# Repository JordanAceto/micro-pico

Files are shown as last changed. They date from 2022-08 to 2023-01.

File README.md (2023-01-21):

# Micro-Pico tiny monosynth

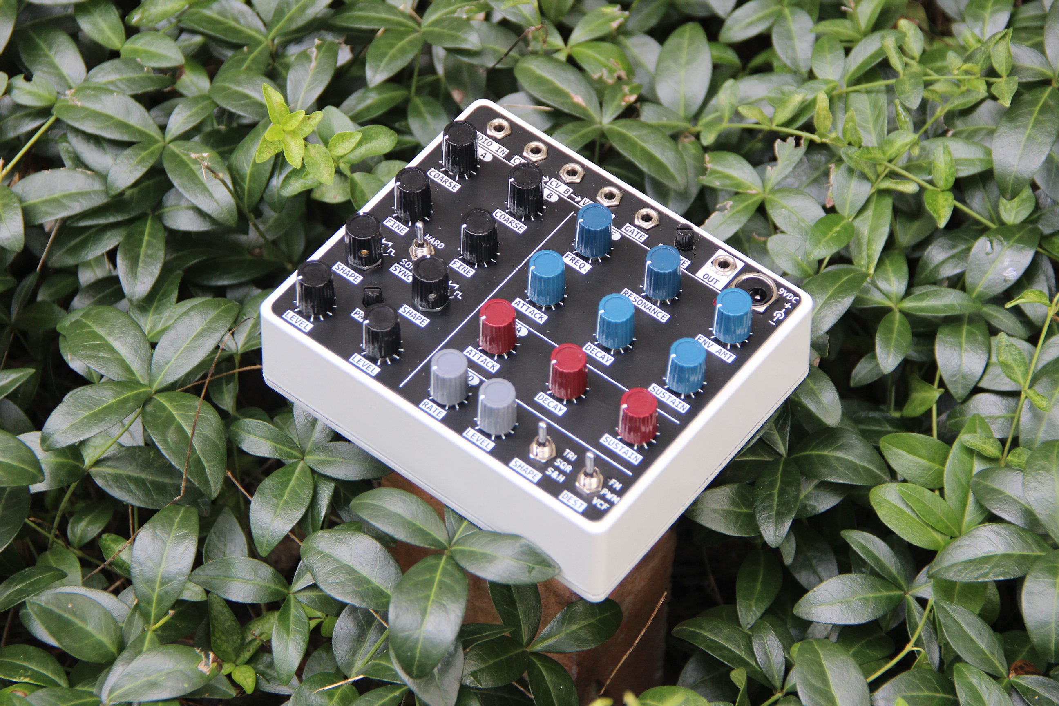
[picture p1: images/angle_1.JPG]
front angle finished synth


## A lil' analog synth with:
- Two SSI2130 VCOs
    - sine, triangle, sawtooth, and pulse waves available
    - VCO B can by syncronized to VCO A (hard and soft sync available)
    - the VCOs share a single manual pulse width control
- Two minimoog style ADS envelope generators
    - These envelopes cycle through all four A, D, S, and R stages, but the Decay and Release stages share a single potentiometer
- Modulation LFO
    - triangle, square, and sample & hold waveforms
    - can be routed to VCO FM, PWM, or VCF modulation
    - `MOD CV` input controlls the LFO depth along with the LFO `LEVEL` knob, for mod-wheel antics
- Swappable VCF port
    - the VCF can be changed by plugging in a variety of [VCF plug-in boards](https://github.com/JordanAceto/VCF_plug_in_boards)
    - you need at least one of the above VCF boards to finish the synth
- Final linear VCA
    - simple linearized SSI2162 VCA
- Extra patch points on the pcb for mods and experimentation
    - independent aux FM inputs for the VCOs [-5v, +5v]
    - aux PWM CV [-5v, +5v]
    - aux VCF cutoff CV [-5v, +5v]
    - aux VCA amplitude CV [0v, +5v]
    - white noise out [-5v, +5v]
    - patch points for most of the important signals
- Powered with a standard guitar pedal style 9VDC center negative adapter
    - current draw is approximately 220mA **without** a VCF plug-in board installed
    - expect another 100mA or so depending on the VCF board used
    - so use a 9v adapter with at least 500mA capacity or greater

The feature set is quite limited. The emphasis is on small, simple, and all-analog signal path. A fun little jammer to hook up to a sequencer or CV keyboard.

## Construction notes:
- It is easier to install the trimpots, VCF port headers, and various through-hole parts before installing the pots and switches
    - you can still get to everything if you forget, or need to change something later
- When installing the front panel components
    - dry fit all of the pots, switches, and jacks before soldering
    - the rotary switches need a nut or spacer under the panel to match the height of the pots
    - the 9VDC connector needs a nut or spacer under the panel, and needs to be lifted off the board a little, so that it protrudes far enough to tighten the outer nut
    - tighten down all of the components, check for alighment and height issues, and only then start soldering
- The rotary switches need a sleeve adapter for the knobs to fit nicely
    - something like [this](https://www.amplifiedparts.com/products/potentiometer-adapter-sleeve-converts-6mm-or-18t-shaft-14)
    - or use a bit of tubing if you're DIY happy
- It's designed to fit in a Hammond 1590XX aluminum box
    - these are available pre-painted in a few colors
    - with a VCF plug-in board installed, the 1590XX is the *teensiest* bit too short, the trimpots hit the lid when tightened
        - you can put some 2mm-ish washers between the lid and the box
        - eventually I hope to make a gasket that adds a few mm height and looks cleaner
        - or it could even have an acrylic light plate like some people do with pedals
    - other chassis at least as big as the 1590XX (plus a few mm taller) could work

## Calibration:
- follow the [SSI2130 datasheet](https://www.soundsemiconductor.com/downloads/ssi2130datasheet.pdf) Tuning Process for the VCOs, or tune by ear
- calibrate the VCF according to the instructions on the main VCF plug-in board repo
- check that the white noise is about +/-5V in amplitude. You can try different BJTs or mess with the gain setting resistors, but as long as it's reasonably close the S&H setting will sound fine, it's not critical

## Status:
Safe to build!

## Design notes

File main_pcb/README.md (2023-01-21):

# Main PCB for tiny monosynth

## [SCHEMATIC](https://github.com/JordanAceto/micro-pico/blob/main/main_pcb/docs/micro_pico-schematic.pdf)

Open `index.html` in a web browser for easy documentation navigation.

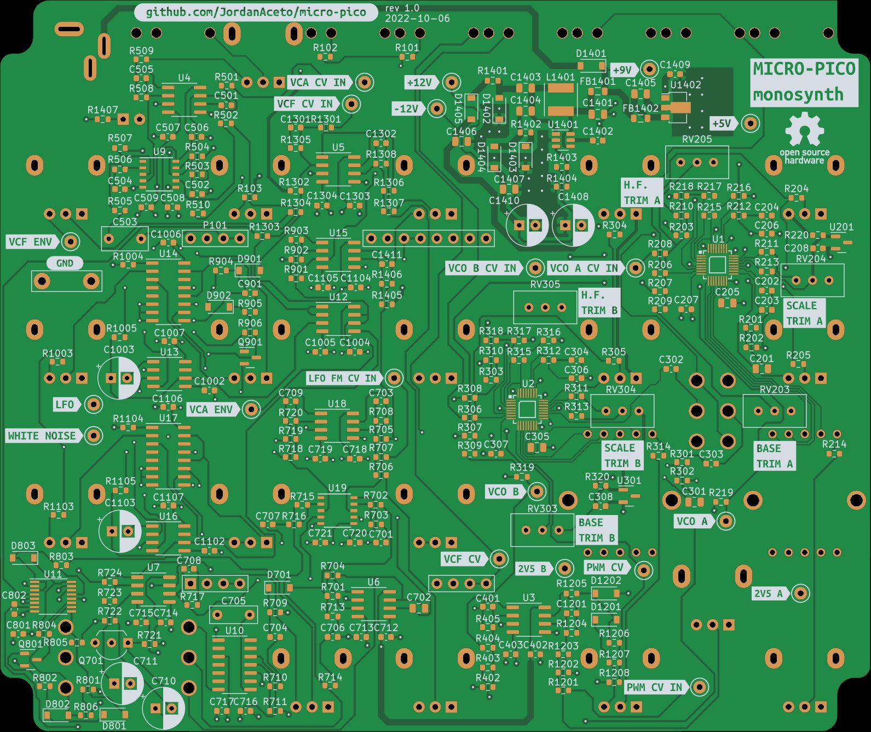
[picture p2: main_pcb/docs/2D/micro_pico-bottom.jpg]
pcb render


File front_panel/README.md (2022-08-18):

# Cheap and cheerful PCB front panel

KiCad 6 project and gerber files for making a front panel.

Open `index.html` in a web browser for easy documentation navigation.

## Important:
- The faceplate material should be 0.8mm or thinner. This ensures that the threaded panel components protrude far enough through the metal faceplate and pcb panel sandwich, so the nuts can be tightened.

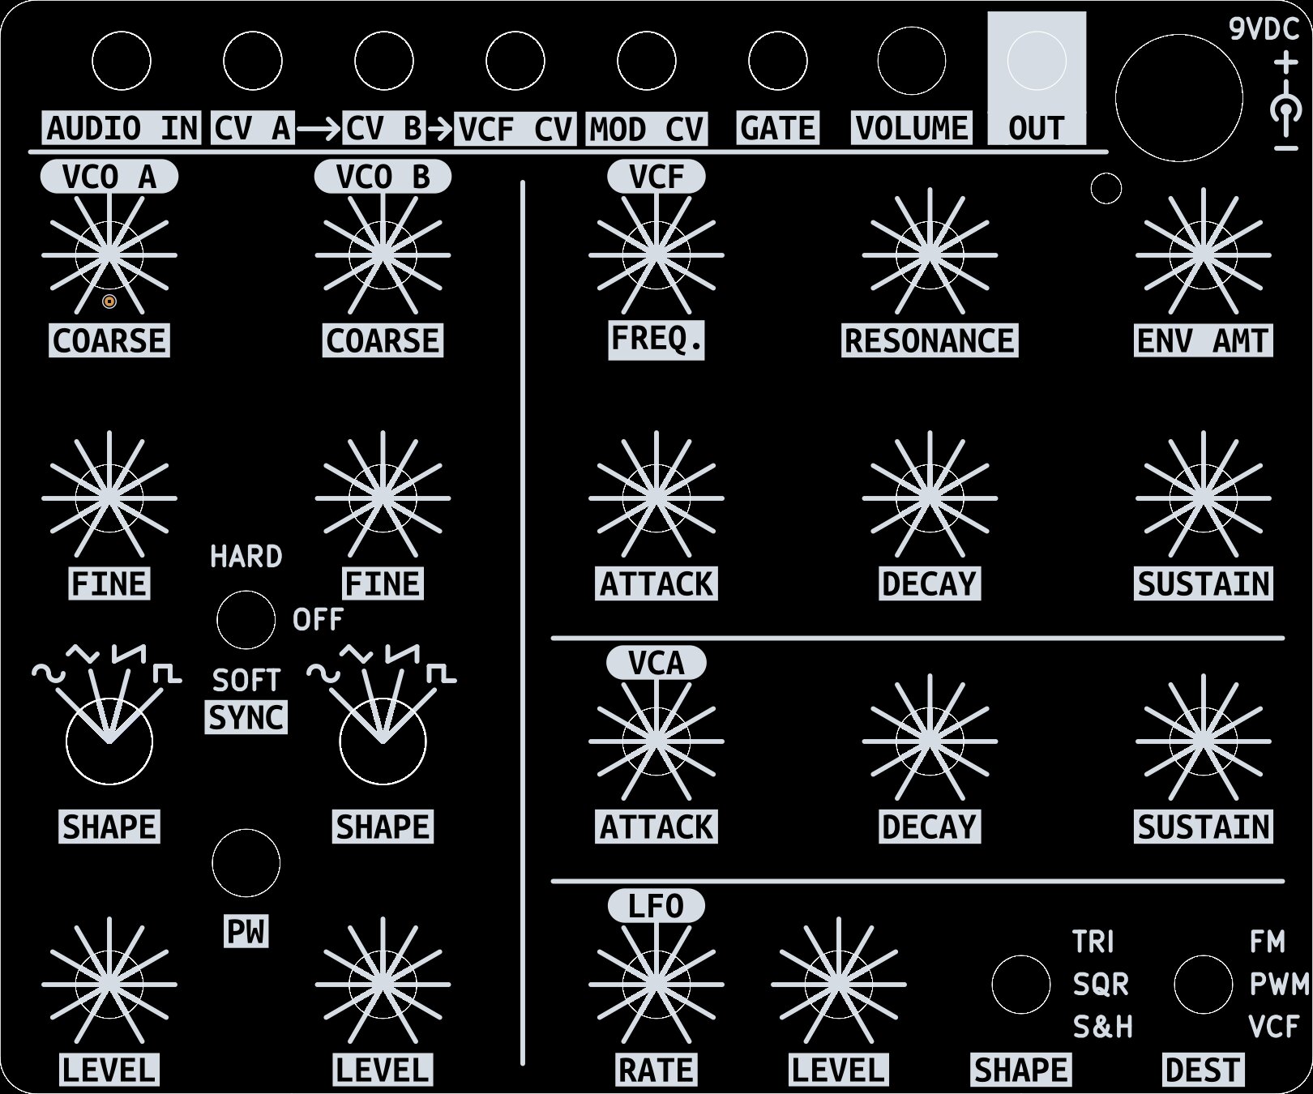
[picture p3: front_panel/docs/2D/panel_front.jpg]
panel render


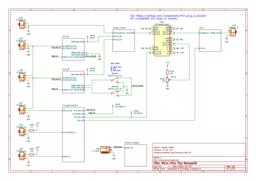
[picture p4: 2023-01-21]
main_pcb/docs/html_nav/images/cat_Schematic_micro_pico-schematic.png

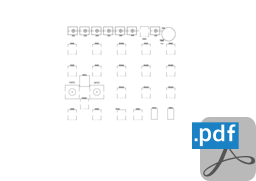
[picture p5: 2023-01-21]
main_pcb/docs/html_nav/images/cat_pdf_layers_micro_pico-F_Silkscreen.png

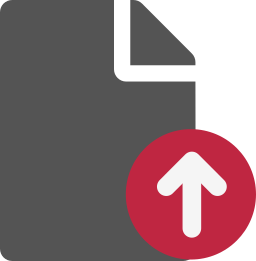
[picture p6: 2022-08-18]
main_pcb/docs/html_nav/images/export_256.png

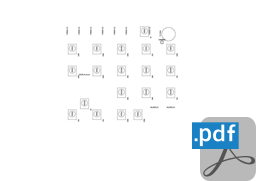
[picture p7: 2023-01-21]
main_pcb/docs/html_nav/images/cat_pdf_layers_micro_pico-F_Fab.png

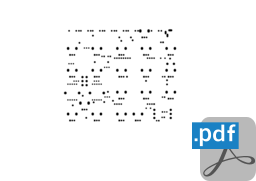
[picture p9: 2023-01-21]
main_pcb/docs/html_nav/images/cat_pdf_layers_micro_pico-F_Mask.png

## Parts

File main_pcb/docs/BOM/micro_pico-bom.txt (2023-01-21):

Row	Description	Part	References	Value	Footprint	Quantity Per PCB	Status	Datasheet
1	Unpolarized capacitor	C	C401 C505 C708 C901 C1302	100p	C_0603_1608Metric	5	 	~
2	Unpolarized capacitor	C	C501 C502 C504 C701 C703 C704 C707 C709 C1002 C1102 C1201 C1301	1n	C_0603_1608Metric	12	 	~
3	Unpolarized capacitor	C	C705	2n2	C_Rect_L7.2mm_W2.5mm_P5.00mm_FKS2_FKP2_MKS2_MKP2	1	 	~
4	Unpolarized capacitor	C	C205 C305	3N9 COG	C_0805_2012Metric	2	 	~
5	Unpolarized capacitor	C	C202 C203 C204 C302 C303 C304	10n	C_0603_1608Metric	6	 	~
6	Unpolarized capacitor	C	C702	10n	C_0805_2012Metric	1	 	~
7	Unpolarized capacitor	C	C206 C207 C208 C306 C307 C308 C402 C403 C506 C507 C508 C509 C706 C712 C713 C714 C715 C716 C717 C718 C719 C720 C721 C801 C802 C1004 C1005 C1006 C1007 C1104 C1105 C1106 C1107 C1303 C1304 C1402 C1409 C1411	100n	C_0603_1608Metric	38	 	~
8	Unpolarized capacitor	C	C1405	470n	C_0805_2012Metric	1	 	~
9	Unpolarized capacitor	C	C503	470n	C_Rect_L7.0mm_W3.5mm_P5.00mm	1	 	~
10	Unpolarized capacitor	C	C1403 C1404	1u	C_0805_2012Metric	2	 	~
11	Unpolarized capacitor	C	C1401 C1406 C1407	4u7	C_0805_2012Metric	3	 	~
12	Polarized capacitor	C_Polarized	C710 C711 C1003 C1103 C1408 C1410	10u	CP_Radial_D6.3mm_P2.50mm	6	 	~
13	Unpolarized capacitor	C	C201 C301	10u	C_0805_2012Metric	2	 	~
14	75V 0.15A Fast Switching Diode, SOD-123	1N4148W	D701 D801 D802 D803 D901 D902 D1201 D1202	1N4148W	D_SOD-123	8	 	https://www.vishay.com/docs/85748/1n4148w.pdf
15	Schottky diode	D_Schottky	D1401 D1402 D1403 D1404 D1405	B5819W	D_SOD-123	5	 	~
16	Light emitting diode	LED	D1406	XLMDK65D	LED_D3.0mm	1	 	~
17	Ferrite bead, small symbol	FerriteBead_Small	FB1401 FB1402	100R @ 100MHz	L_0805_2012Metric	2	 	~
18	DC Barrel Jack with an internal switch	PJ-011A	J108	PJ-011A	CUI_PJ-011A	1	 	~
19	Audio Jack, 2 Poles (Mono / TS), Switched T Pole (Normalling)	PJ301M-12	J101 J102 J103 J104 J105 J106 J107	PJ301M-12	PJ301M-12	7	 	~
20	Inductor symbol for simulation only	INDUCTOR	L1401	10uH, 1.2A	L_Taiyo-Yuden_NR-50xx	1	 	~
21		VCF_plug_in_port	P101	VCF_plug_in_port	VCF_plug_in_port	1	 	
22	0.2A Ic, 40V Vce, Small Signal NPN Transistor, TO-92	2N3904_wide	Q701	2N3904_wide	TO-92_Inline_Wide	1	 	https://www.onsemi.com/pub/Collateral/2N3903-D.PDF
23	0.2A Ic, 40V Vce, Small Signal NPN Transistor, SOT-23	MMBT3904	Q801 Q901	MMBT3904	SOT-23	2	 	https://www.onsemi.com/pub/Collateral/2N3903-D.PDF
24	Resistor	R	R1401 R1402	1	R_0603_1608Metric	2	 	~
25	Resistor	R	R1004 R1005 R1104 R1105	100	R_0603_1608Metric	4	 	~
26	Resistor	R	R212 R312 R503 R506 R509 R703 R716	270	R_0603_1608Metric	7	 	~
27	Resistor	R	R101 R220 R320 R723 R803 R1205	1k	R_0603_1608Metric	6	 	~
28	Resistor	R	R215 R315	3k9	R_0603_1608Metric	2	 	~
29	Resistor	R	R216 R218 R316 R318 R507 R711	4k7	R_0603_1608Metric	6	 	~
30	Resistor	R	R1003 R1103	5k6	R_0603_1608Metric	2	 	~
31	Resistor	R	R1208	6k8	R_0603_1608Metric	1	 	~
32	Resistor	R	R102 R103 R201 R202 R301 R302 R709 R801 R802 R804 R805 R806 R904 R906 R1206 R1407	10k	R_0603_1608Metric	16	 	~
33	Resistor	R	R217 R317 R508 R710 R902	12k	R_0603_1608Metric	5	 	~
34	Resistor	R	R1404	13k3	R_0603_1608Metric	1	 	~
35	Resistor	R	R219 R319	18k	R_0603_1608Metric	2	 	~
36	Resistor	R	R702 R1305	22k	R_0603_1608Metric	2	 	~
37	Resistor	R	R403 R404 R505	27k	R_0603_1608Metric	3	 	~
38	Resistor	R	R203 R303 R708	39k	R_0603_1608Metric	3	 	~
39	Resistor	R	R211 R311 R713 R714	47k	R_0603_1608Metric	4	 	~
40	Resistor	R	R720 R1207 R1304	56k	R_0603_1608Metric	3	 	~
41	Resistor	R	R705	68k	R_0603_1608Metric	1	 	~
42	Resistor	R	R206 R207 R208 R209 R214 R306 R307 R308 R309 R314 R402 R405 R501 R504 R704 R706 R715 R717 R718 R719 R901 R903 R905 R1301 R1302 R1303 R1306 R1308 R1405 R1406	100k	R_0603_1608Metric	30	 	~
43	Resistor	R	R1403	114k	R_0603_1608Metric	1	 	~
44	Resistor	R	R502 R721	150k	R_0603_1608Metric	2	 	~
45	Resistor	R	R204 R304 R707	200k	R_0603_1608Metric	3	 	~
46	Resistor	R	R701 R1203 R1204 R1307	220k	R_0603_1608Metric	4	 	~
47	Resistor	R	R210 R310	270k	R_0603_1608Metric	2	 	~
48	Resistor	R	R1201 R1202	330k	R_0603_1608Metric	2	 	~
49	Resistor	R	R213 R313	470k	R_0603_1608Metric	2	 	~
50	Resistor	R	R205 R305 R722	2M2	R_0603_1608Metric	3	 	~
51	Resistor	R	R510 R724	10M	R_0603_1608Metric	2	 	~
52	Potentiometer	R_Potentiometer	RV501 RV1201	5k	Bourns_PTV09	2	 	~
53	Trim-potentiometer	R_Potentiometer_Trim	RV203 RV204 RV205 RV303 RV304 RV305	5k	Potentiometer_Bourns_3296W_Vertical	6	 	~
54	Potentiometer	R_Potentiometer	RV101 RV206 RV306 RV1003 RV1103	10k	Alpha_RD901F	5	 	~
55	Potentiometer	R_Potentiometer	RV201 RV202 RV301 RV302 RV601 RV602 RV701 RV1301	100k	Alpha_RD901F	8	 	~
56	Potentiometer	R_Potentiometer	RV1001 RV1002 RV1101 RV1102	1MA	Alpha_RD901F	4	 	~
57	3 rotary switches with 4 positions	SR1712F-0204	SW201 SW301	SR1712F-0204	SR1712F_rotary_switch	2	 	
58	Switch, dual pole double throw, separate symbols	SW_DP_on_on_on	SW101	SW_DP_on_on_on	DPDT_mini_toggle	1	 	~
59	Switch, single pole double throw, center OFF position	SW_SPDT_MSM	SW701 SW801	SW_SPDT_CO	SPDT_mini_toggle	2	 	~
60	CMOS double 4-channel analog multiplexer/demultiplexer, TSSOP-16/DIP-16/SOIC-16	CD4052B	U14 U17	CD4052B	SOIC-16_3.9x9.9mm_P1.27mm	2	 	http://www.ti.com/lit/ds/symlink/cd4052b.pdf
61	Triple analog Multiplexer 2 to 1 line	4053	U11	CD4053	TSSOP-16_4.4x5mm_P0.65mm	1	 	http://www.intersil.com/content/dam/Intersil/documents/cd40/cd4051bms-52bms-53bms.pdf
62	Positive 100mA 30V Linear Regulator, Fixed Output 5V, SOT-89	L78L05_SOT89	U1402	L78L05_SOT89	SOT-89-3	1	 	http://www.st.com/content/ccc/resource/technical/document/datasheet/15/55/e5/aa/23/5b/43/fd/CD00000446.pdf/files/CD00000446.pdf/jcr:content/translations/en.CD0000044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
63	Sample And Hold Unity Gain Follower, SOIC-14	LF398_SOIC14	U10	LF398_SOIC14	SOIC-14_3.9x8.7mm_P1.27mm	1	 	http://www.ti.com/lit/ds/symlink/lf398-n.pdf
64	2.500V Precision Micropower Shunt Voltage Reference, SOT-23	LM4040DBZ-2.5	U201 U301	LM4040C-2.5	SOT-23	2	 	http://www.ti.com/lit/ds/symlink/lm4040-n.pdf
65		LT3467A	U1401	LT3467A	TSOT-23-6	1	 	
66		SSI2130	U1 U2	SSI2130	PQN32_HandSoldering	2	 	
67		SSI2162	U9 U19	SSI2162	SSOP-10_3.9x4.9mm_P1.00mm	2	 	https://www.soundsemiconductor.com/downloads/ssi2162datasheet.pdf
68	Dual Low-Noise JFET-Input Operational Amplifiers, DIP-8/SOIC-8	TL072	U3 U4 U5 U6 U7 U12 U15 U18	TL072	SOIC-8_3.9x4.9mm_P1.27mm	8	 	http://www.ti.com/lit/ds/symlink/tl071.pdf
69	Timer, 555 compatible, SOIC-8	LM555xM	U13 U16	TLC555	SOIC-8_3.9x4.9mm_P1.27mm	2	 	

Project info:
Schematic:	micro_pico
Variant:	default
Revision:	1.0
Date:	2022-10-06
KiCad Version:	6.0.5+dfsg-1~bpo11+1
Statistics:
Component Groups:	69
Component Count:	282 (221 SMD/ 48 THT)
Fitted Components:	282 (221 SMD/ 48 THT)
Number of PCBs:	1
Total Components:	282

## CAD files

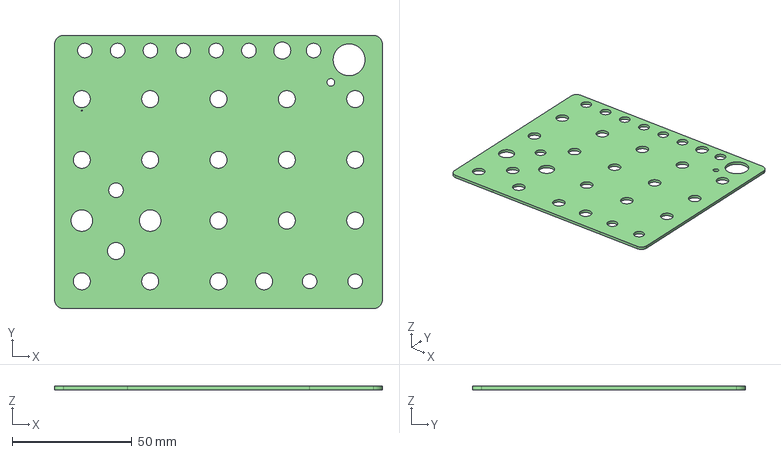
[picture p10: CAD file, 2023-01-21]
front_panel/docs/CAD/micro_pico_faceplate-3D.step
137.2 x 114.3 x 1.60 mm

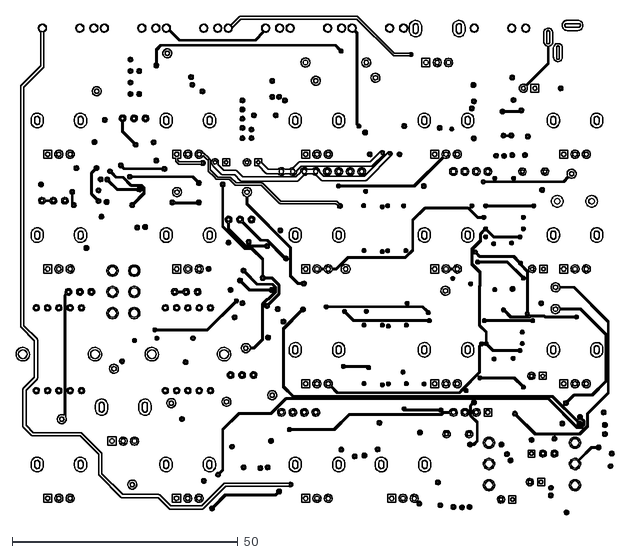
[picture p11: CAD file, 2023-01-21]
main_pcb/docs/CAD/micro_pico-F_Cu.dxf
132.4 x 110.3

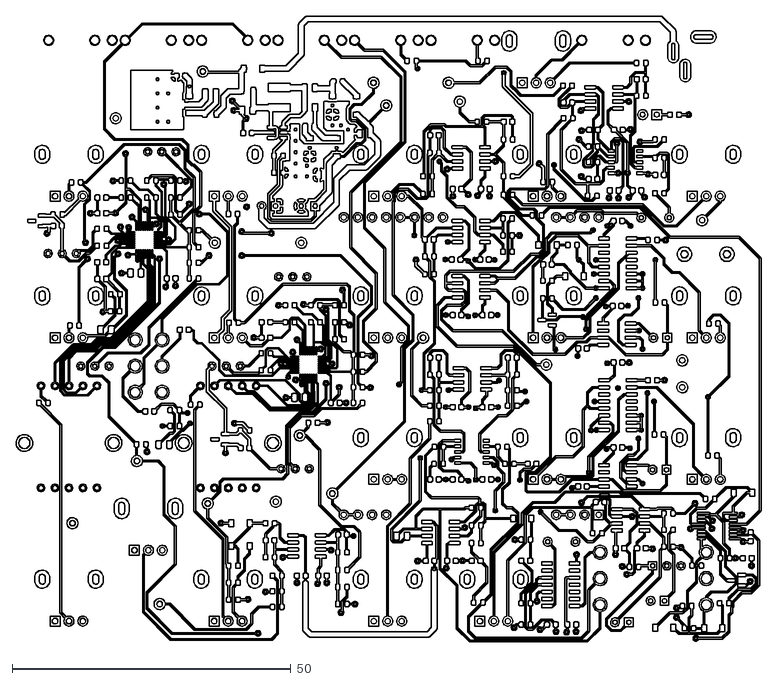
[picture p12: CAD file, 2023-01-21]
main_pcb/docs/CAD/micro_pico-B_Cu.dxf
133.6 x 112.2

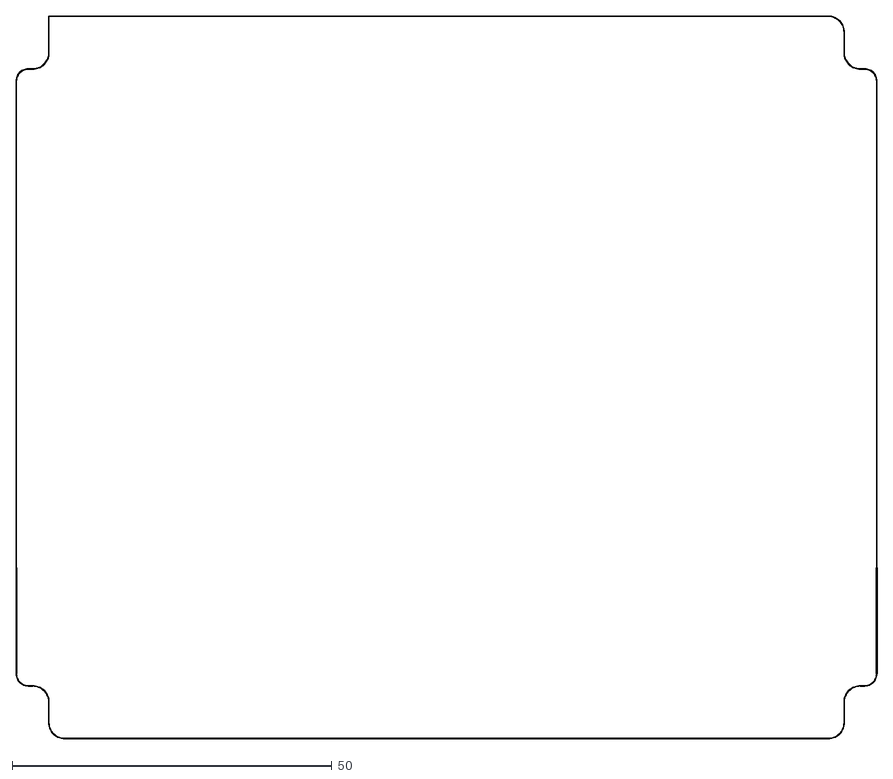
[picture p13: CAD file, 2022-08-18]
main_pcb/docs/CAD/micro_pico-Edge_Cuts.dxf
134.7 x 113.1

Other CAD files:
main_pcb/docs/CAD/micro_pico-B_Mask.dxf
main_pcb/docs/CAD/micro_pico-F_Mask.dxf
main_pcb/docs/CAD/micro_pico-F_Silkscreen.dxf

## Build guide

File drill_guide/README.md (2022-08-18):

# Drill guide for the front panel holes

Print out 1-to-1 and double sticky tape to the front panel to locate the drill holes.

On my printer, I have the best luck getting the scaling right by printing the gerber file from KiCads gerber viewer.

drill guide

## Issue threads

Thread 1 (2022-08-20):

VCA tails are a bit abrupt with low volume settings

JordanAceto, 2022-08-20:
On the final VCA, resistor R510 ensures that when zero volts is applied to the CV input, the output signal is completely silenced. It "pushes down" the CV input by a tiny bit.

But if too much current flows through this resistor, it can make the long tails of the volume envelope end abruptly. The final decay doesn't sound as smooth as it should.

Since 10M is already a very large resistor value, it would be an improvement to move this resistor to the -2V5 reference voltage. This will reduce the effect of the push-down resistor, and if we find that there is bleedthrough with zero CV, we can decrease the resistor a little bit.

This should allow us some flexibility while being able to use common resistor values.

Another way to tackle this might be to change the way the volume pot works: right now the volume pot turns up and down the control voltage that goes to the final VCA. This means when the volume is turned down low, the ADSR signal is small relative to the impact of the push-down resistor. If instead we always sent the ADSR signal to the VCA CV full-strength, and then attenuated the signal before or after the VCA, I think the un-smooth decay effect would be reduced.

As a side benefit of the "attenuate the signal instead of the CV" approach: there is an aux VCA CV input on the PCB, if we use that input the way it's wired now, the volume control will have no effect. If we change to a signal attenuator, then the volume control will always work no matter the CV source.

JordanAceto, 2022-09-09:
Done, changed the way the volume pot works, now it attenuates the final audio out instead of the control signal. Left the 10M push-down resistor in, it is not a problem with the new arrangement.

Closed 2022-09-09.

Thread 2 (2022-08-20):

Volume pot and manual Pulse Width pot are different type

JordanAceto, 2022-08-20:
Most of the potentiometers use common alpha RD901F style pots with a knob attached.

The master volume pot and manual pulse width pot are very cramped for space, so they use pots with knurled plastic shafts, intended to be turned with no knob attached. I used [bourns PTV09A](https://www.bourns.com/pdfs/PTV09.pdf) pots on the prototype build, anything similar to this would work.

This is not currently reflected in any of the schematic, pcb layout, or BOM files, all the pots are listed as the same RD901F style.

Also, the Bourns pots I used had snap-in tabs that were a little bit too wide to fit in the RD901F footprint, I had to clip a tiny bit off the sides of the snap-in tabs to get them to fit.

Update the files so the correct type of pot is specified for the master volume and manual PW pot, and update the footprints for these two pots with slightly longer snap-in tab slots so we don't need to mess around when installing the pots.

JordanAceto, 2022-09-09:
Done, changed footprints for the knob-less pots.

Closed 2022-09-09.

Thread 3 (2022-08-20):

VCOs occasionally frequency lock

JordanAceto, 2022-08-20:
When the two VCOs are tuned very close to each other, they *sometimes* lock together, instead of beating slowly.

This isn't something super noticeable while you're playing it, but it would be better if you could dial in nice slow beat frequencies all the time.

I imagine this is happening via coupling through the 2v5 reference voltage which they share.

Maybe they should each get their own 2v5 reference? The LM4040 used are not super expensive, and they are small so board real estate is not a big deal.

You might also be able to put a little more current through the +2v5 ref LM4040 and see if that helps.

Something else that *might* help is to remove the extra 2v5 ref loads, a few pots and such use the 2v5 ref. We could use an opamp buffer to decouple the 2v5 ref which goes to the SSI2130 `vref` pin and the 2v5 which goes to the pots and stuff. Note that we use two opamp comparators for the ADSR gate inputs, but really they could share one, we could free up an opamp from there if needed.

Investigate and find a good solution. The **best** one would be to just run the LN4040 a little hotter *if it fixes it*, because this doesn't require any new parts or pcb changes.

JordanAceto, 2022-09-08:
After some investigation, I believe the frequency locking is actually coming from the SYNC switch. The VCO_A_PULSE signal is being capacitively injected into the VCO B SOFT_SYNC_IN pin.

Pulling the VCO B SOFT_SYNC_IN pin to ground with a resistor seems to help. On the current prototype there is a 1k ohm resistor kludged from the VCO B SSI2132 soft sync pin to ground. This helps, but does not prevent unwanted syncing all the time. Hard-grounding the soft-sync capacitor does seem to reliably prevent it. The higher the frequency of the VCOs, the more likely they are to sync.

Maybe I need a fancier switch which can ground the sync inputs when sync is off? I'm not even that huge of a sync-lover, maybe there should just be one option instead of the current HARD-OFF-SOFT sync switch. Continue to investigate and think about this.

JordanAceto, 2023-01-21:
Fixed by changing the sync switch to a type that grounds the unused sync inputs.

Closed 2023-01-21.

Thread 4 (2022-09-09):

Add LFO depth CV input

JordanAceto, 2022-09-09:
It would be really nice if there was a CV input jack for LFO depth. This would let you use a mod-wheel CV signal from a keyboard controller in the classic fashion. The popular Arturia Keystep is already set up with this mod output jack.

This would require adding another VCA, but I think there is plenty of room on the PCB. It also requires another jack on the panel, which is a little tighter for space. See if there is enough room to squeeze another jack in.

When I was making this, my whole goal was to play the [Flashlight](https://www.youtube.com/watch?v=E5uH1JFcaq8) bass line from Parliament on a ridiculously small synth because I thought it would be fun. But you really need that mod-wheel to get the full effect!

JordanAceto, 2023-01-21:
Added!

Closed 2023-01-21.

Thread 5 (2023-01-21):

R507 is in the wrong place

JordanAceto, 2023-01-21:
This one isn't a huge deal, but if there is another revision it should be addressed:

R507 goes between the VCA CV generating opamp and the control port of the SSI2162 VCA which attenuates the audio.

BUT it **should** go between the output of U4B and **both** of the CV inputs of the SSI2162 sections as shown below.

The job of this resistor is to limit the power dissipated in the SSI2162 at maximum attenuation. The output of U4B shoots positive at max attenuation (which happens with large positive CV signals) and the SSI2162 consumes more current than is necessary.

This is a small problem, and it's ok to leave it as it is for now and build new ones with the current design. Many existing SSI216x designs do not include this resistor. Don't scrap any existing boards because of this, but do change it during the next revision.

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

JordanAceto, 2023-02-10:
Note that there is a recent update to the SSI216x datasheet showing a PNP transistor clamp in this position. Check it out and consider which way to go before updating the board:

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

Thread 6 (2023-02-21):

ADSRs can occasionally get stuck

JordanAceto, 2023-02-21:
The two ADSR envelope generators use CD4052 analog switches to steer the charging and discharging of a capacitor to create the envelope shape.

All of the expected states are wired up so everything works as expected. But I did not wire up the pins for the states which will "never happen", I left those pins open. See the schematic image below. The `(1, 0)` state for the analog switch logic is not fully defined, and if the switch ever goes into the `(1, 0)` state the charging capacitor is left open, holding whatever charge is stored in it.

Note that the open Y3 pin 4 is not a problem, because in state `(1, 1)` the capacitor is coupled directly to the ATTACK pot and the lower switch section doesn't matter. It's pins X1 and Y1 that are relevant.

Everything works fine for the most part, but I have managed to occasionally lock up the envelopes with attack times that are longer than the incoming gate. This seems to be potentially related to the brand of 555 timer, but this is not conclusive.

If this is a problem, an easy kludge is to short pin 14 to 15, and also short pin 1 to 5. This makes it so that if we ever go into this odd state the envelope enters the RELEASE/AT REST phase, which is better than getting stuck in an undefined state.

Future board revisions should connect these pins as described. The analog switch logic table should become:
| 4052 logic     | A | B |
| ----------- | ----------- | ----------- |
| At rest/Release | don't care | 0 |
| Attack  | 1 | 1 |
| Decay/Sustain | 0 | 1 |

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

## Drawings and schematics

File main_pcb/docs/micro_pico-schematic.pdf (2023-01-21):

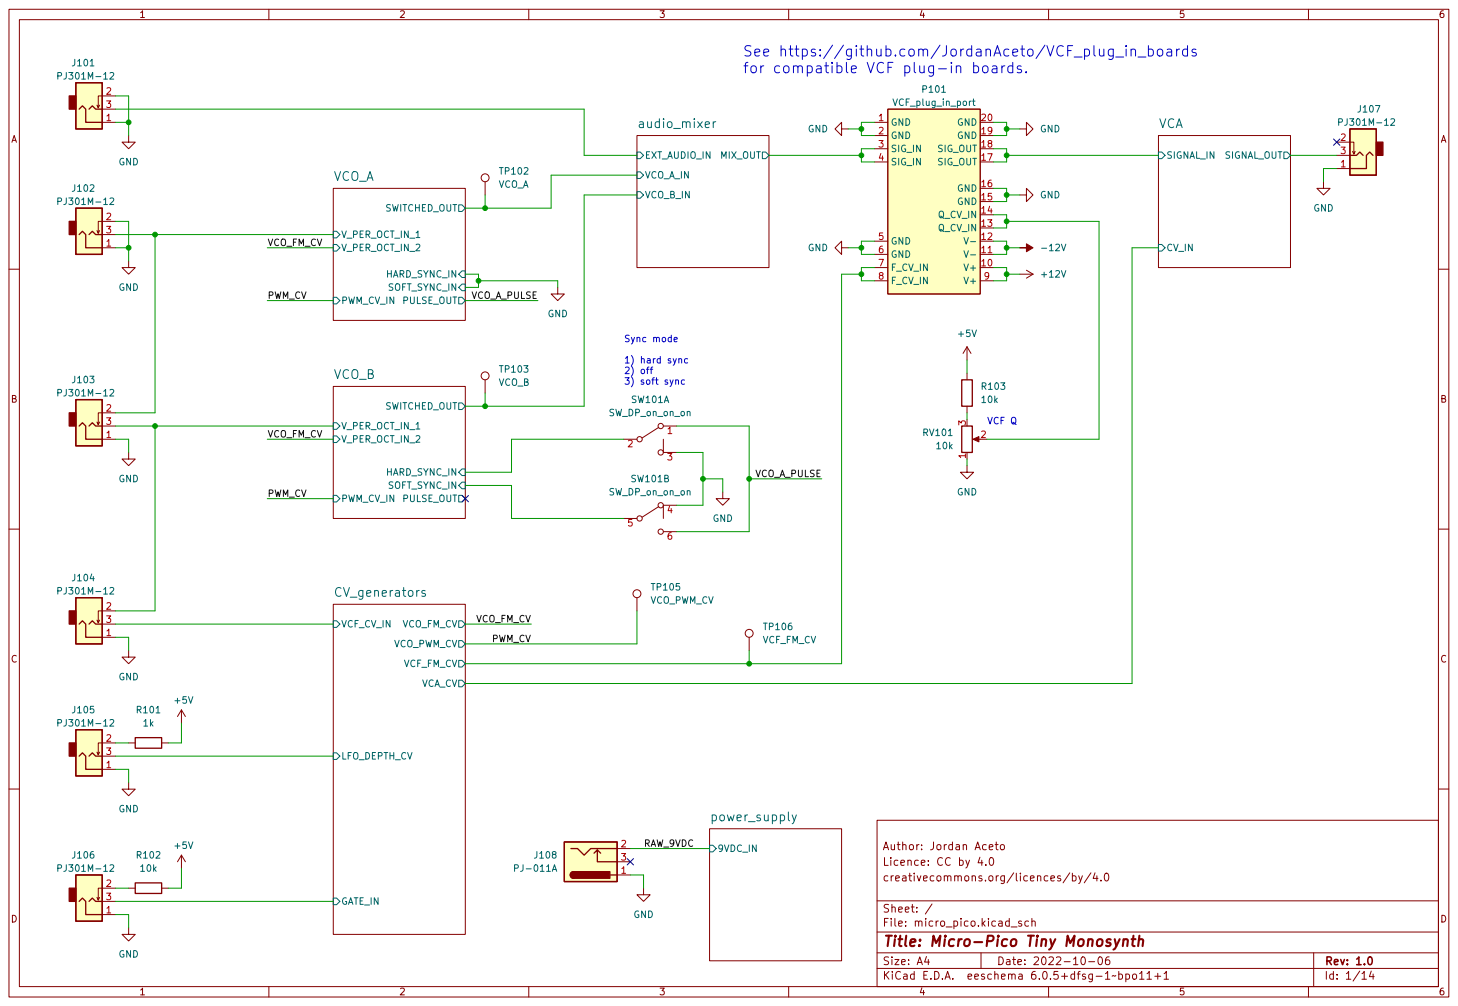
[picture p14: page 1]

See https://github.com/JordanAceto/VCF_plug_in_boards
for compatible VCF plug-in boards.

Licence: CC by 4.0 Author: Jordan Aceto

File: micro_pico.kicad_sch Sheet: / creativecommons.org/licences/by/4.0

Id: 1/14 Title: Micro-Pico Tiny Monosynth

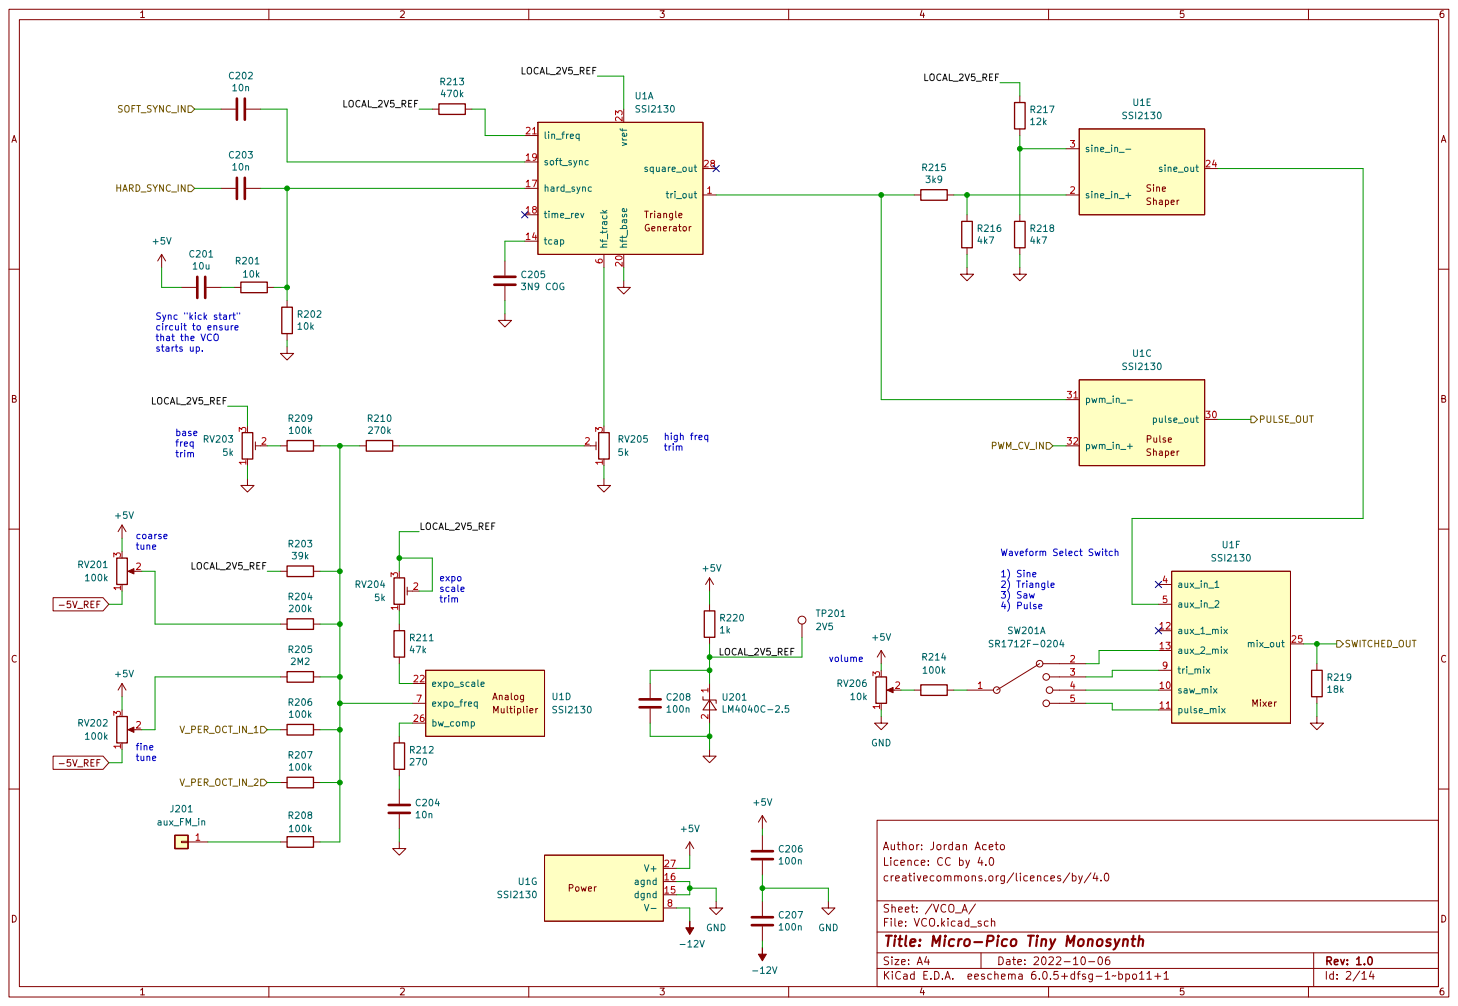
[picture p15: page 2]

Sync "kick start" circuit to ensure

Licence: CC by 4.0 Author: Jordan Aceto C204

creativecommons.org/licences/by/4.0

Sheet: /VCO_A/
File: VCO.kicad_sch
Id: 2/14 Title: Micro-Pico Tiny Monosynth

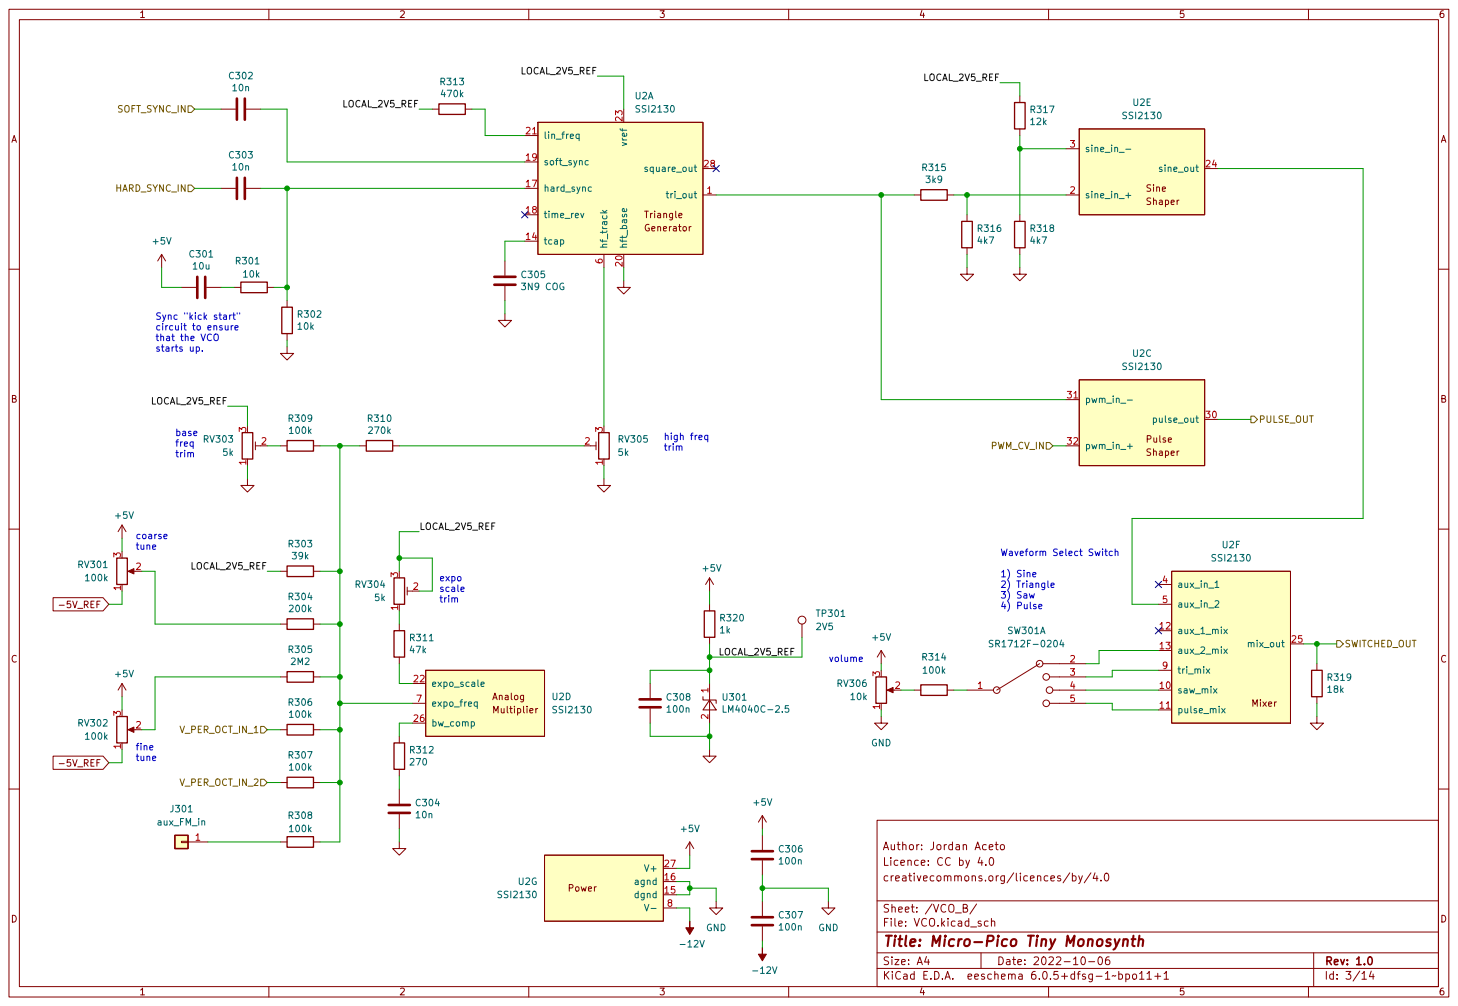
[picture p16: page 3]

Sync "kick start" circuit to ensure

Licence: CC by 4.0 Author: Jordan Aceto C304

creativecommons.org/licences/by/4.0

Sheet: /VCO_B/
File: VCO.kicad_sch
Id: 3/14 Title: Micro-Pico Tiny Monosynth

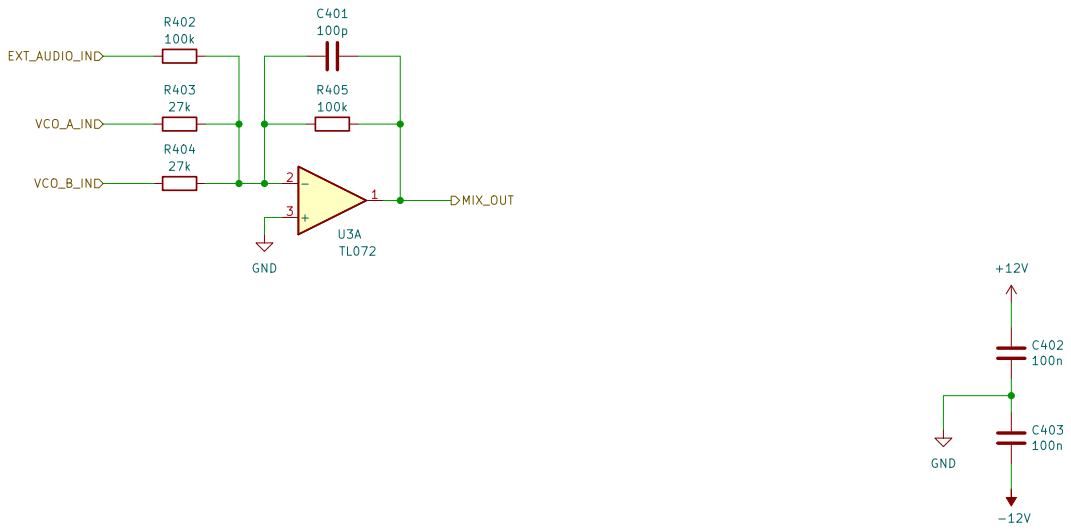
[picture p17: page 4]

creativecommons.org/licences/by/4.0

Sheet: /audio_mixer/
File: audio_mixer.kicad_sch
Id: 4/14 Title: Micro-Pico Tiny Monosynth

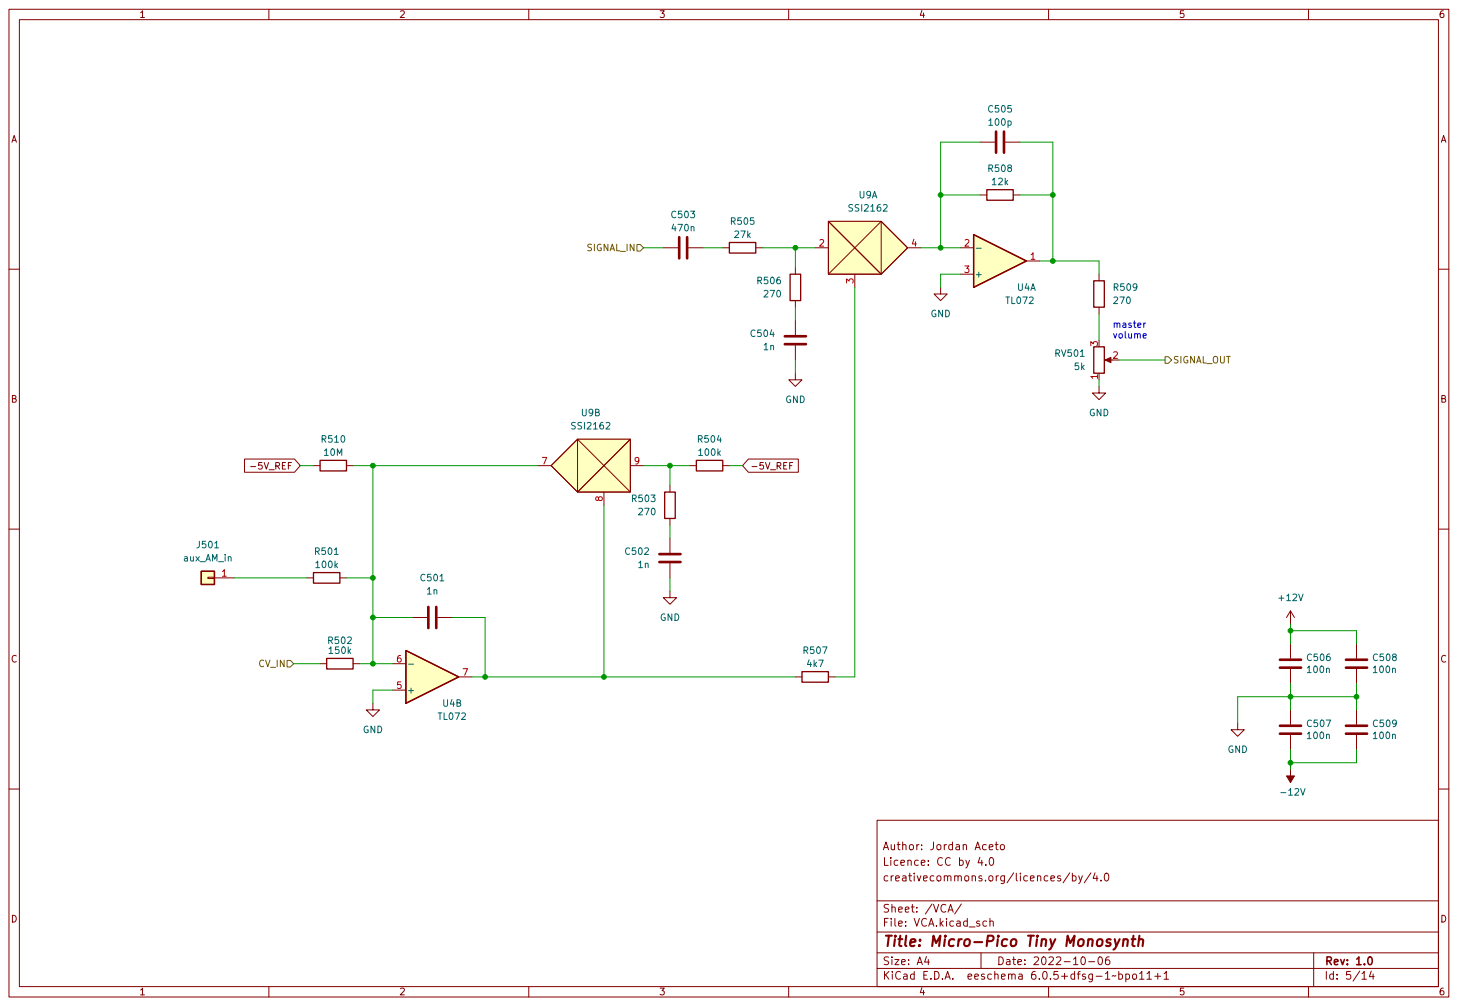
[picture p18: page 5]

File: VCA.kicad_sch Sheet: /VCA/ creativecommons.org/licences/by/4.0

Id: 5/14 Title: Micro-Pico Tiny Monosynth

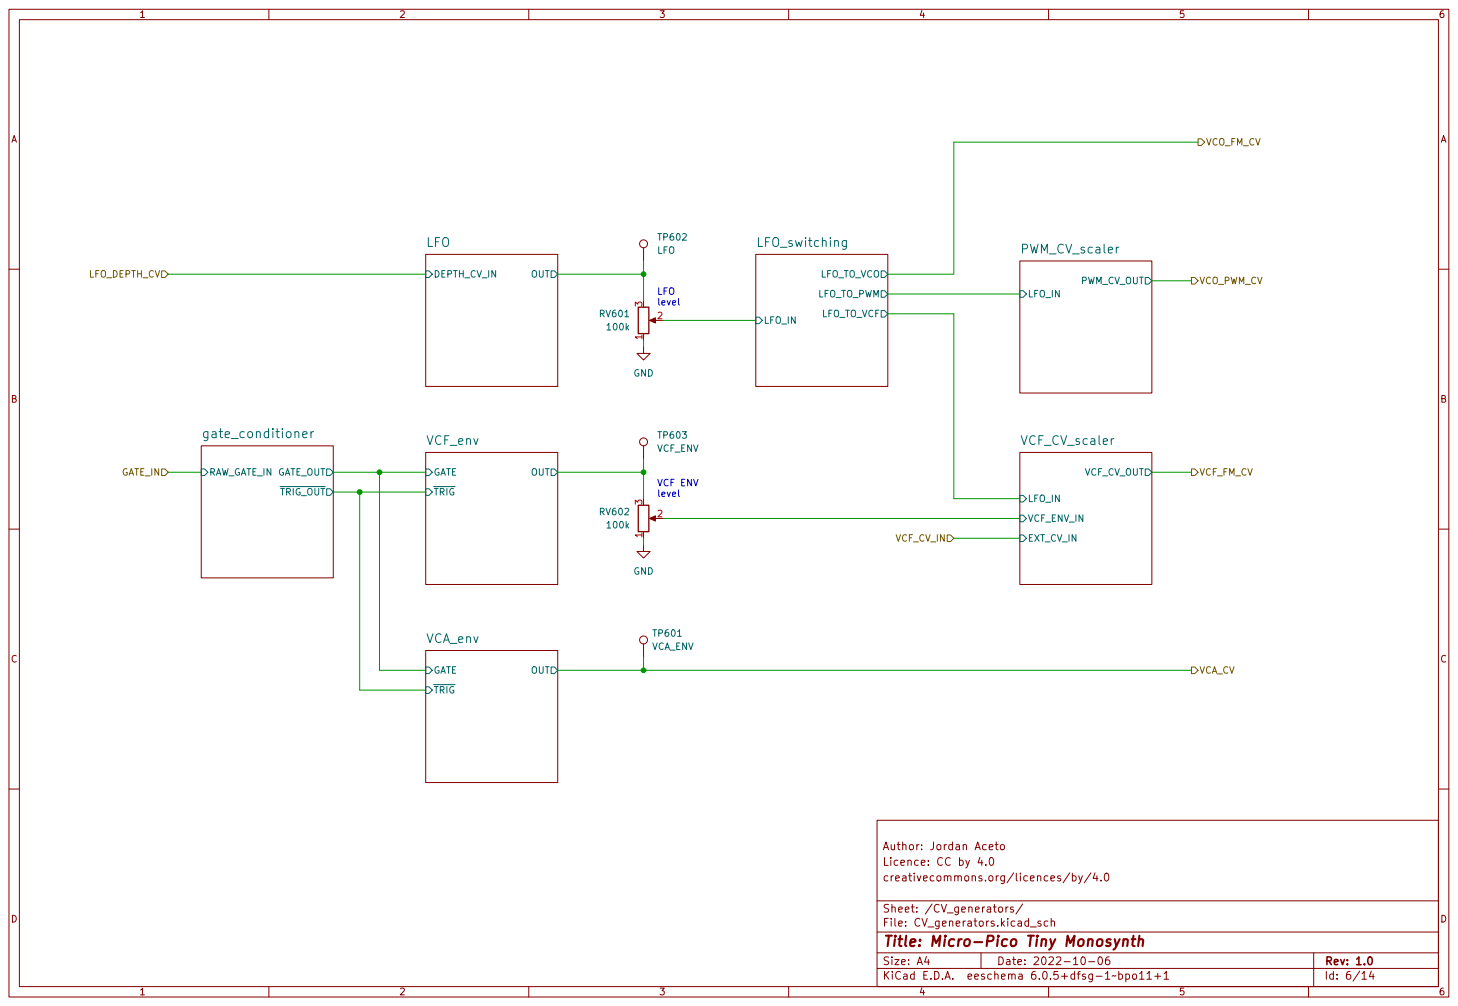
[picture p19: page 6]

Licence: CC by 4.0 Author: Jordan Aceto

creativecommons.org/licences/by/4.0

Sheet: /CV_generators/
File: CV_generators.kicad_sch
Id: 6/14 Title: Micro-Pico Tiny Monosynth

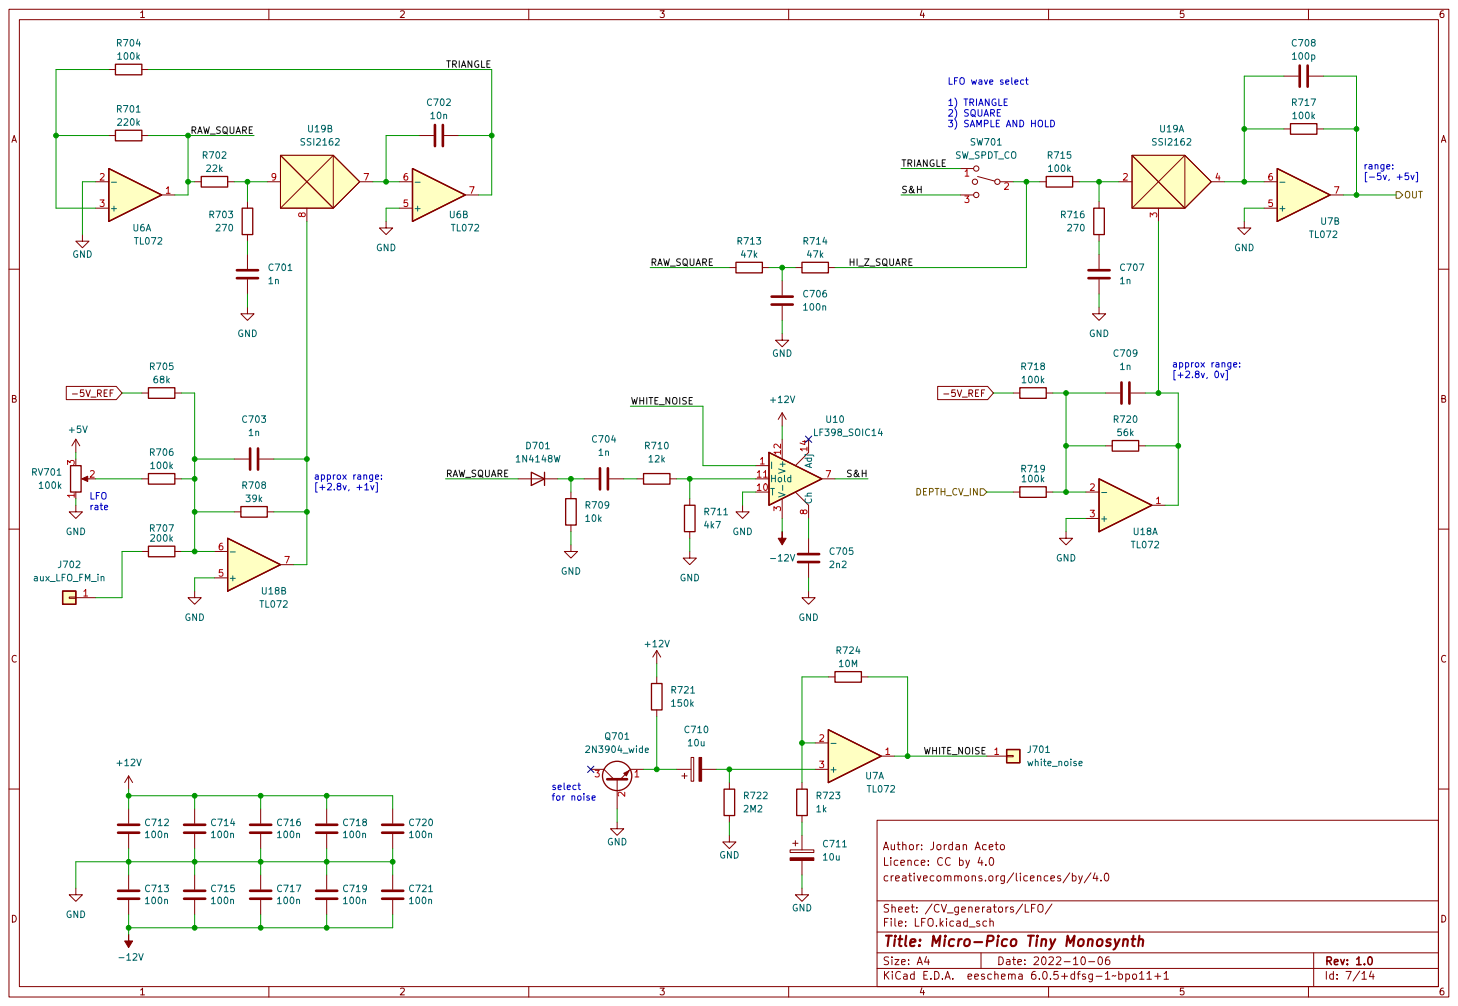
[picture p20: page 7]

LFO wave select 1) TRIANGLE

Licence: CC by 4.0 Author: Jordan Aceto

creativecommons.org/licences/by/4.0

Sheet: /CV_generators/LFO/
File: LFO.kicad_sch
Id: 7/14 Title: Micro-Pico Tiny Monosynth

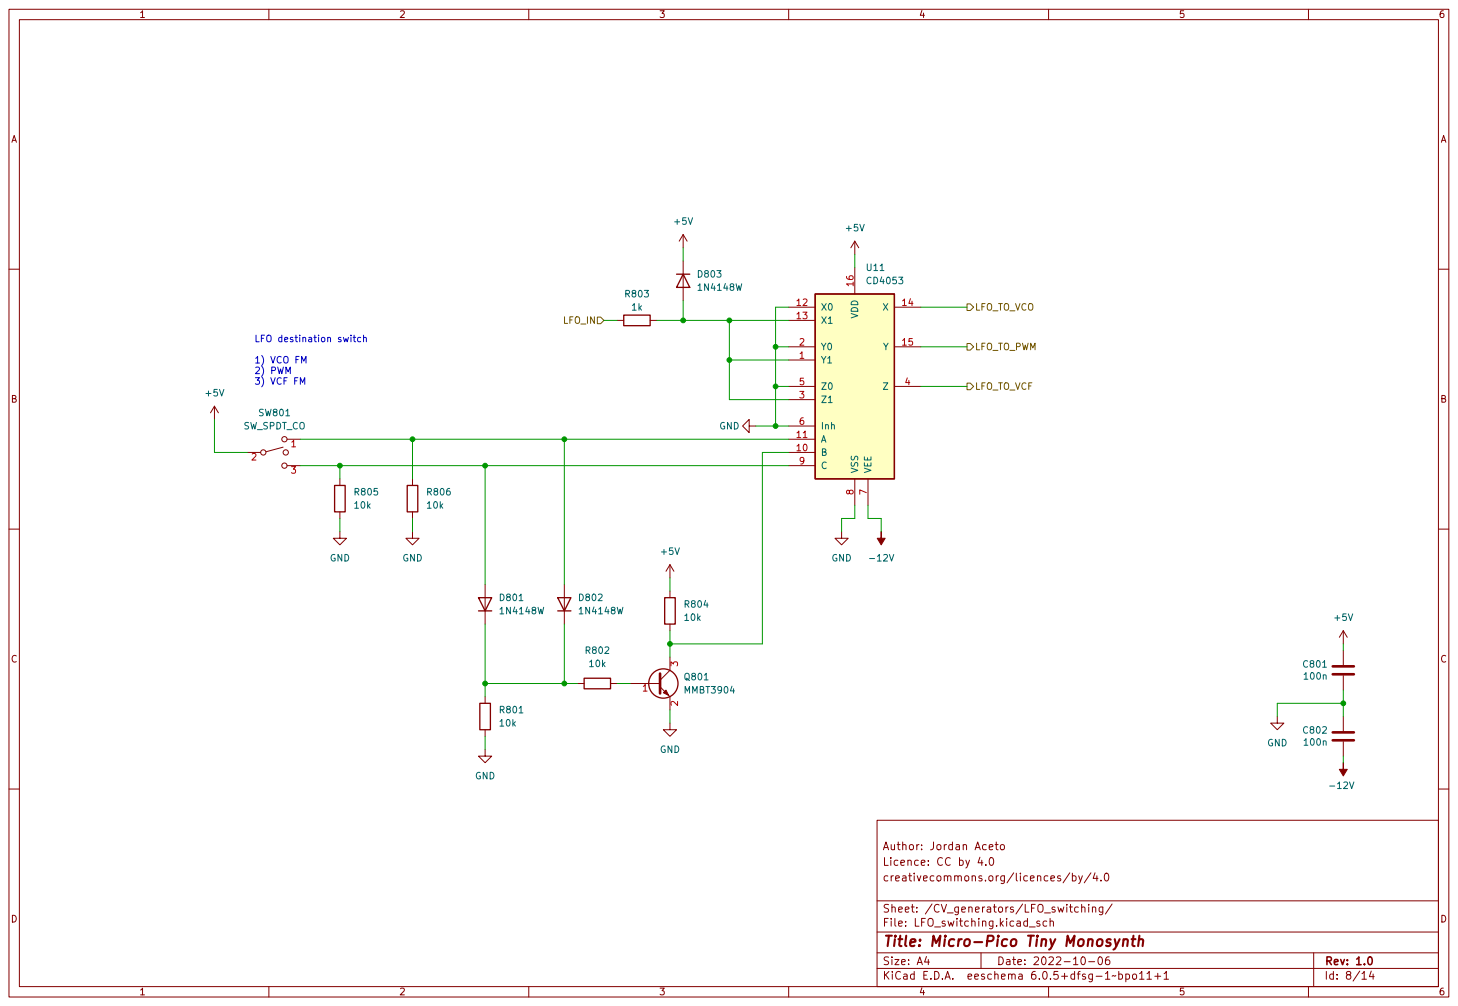
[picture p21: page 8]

creativecommons.org/licences/by/4.0

Sheet: /CV_generators/LFO_switching/
File: LFO_switching.kicad_sch
Id: 8/14 Title: Micro-Pico Tiny Monosynth

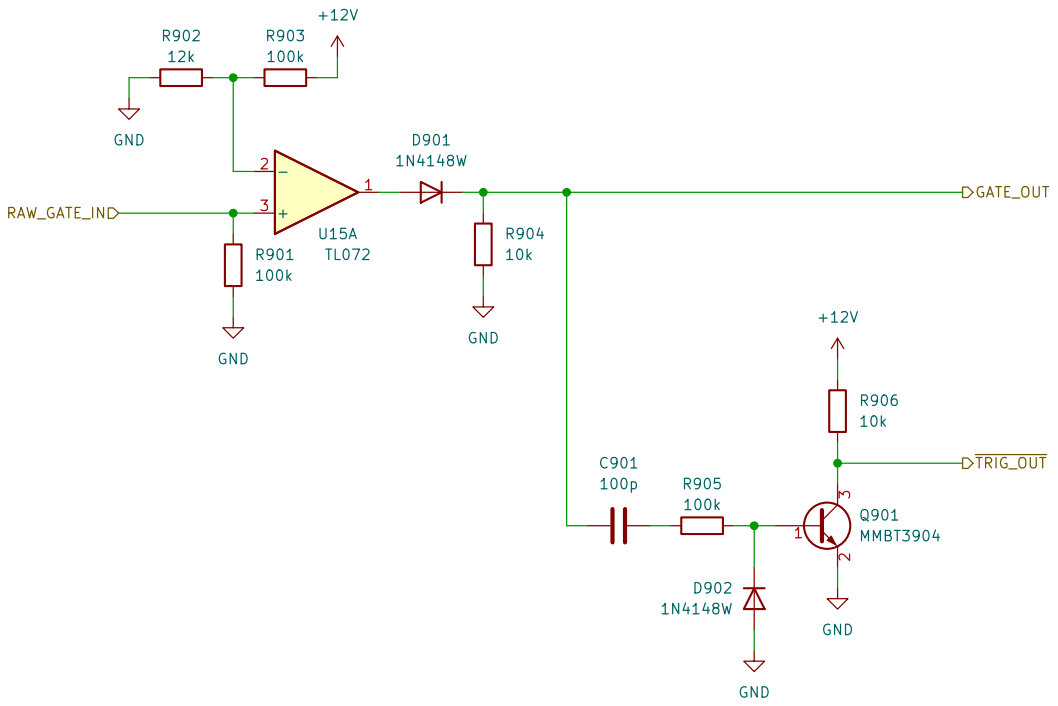
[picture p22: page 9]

Licence: CC by 4.0 Author: Jordan Aceto

creativecommons.org/licences/by/4.0

Sheet: /CV_generators/gate_conditioner/
File: gate_conditioner.kicad_sch
Id: 9/14 Title: Micro-Pico Tiny Monosynth

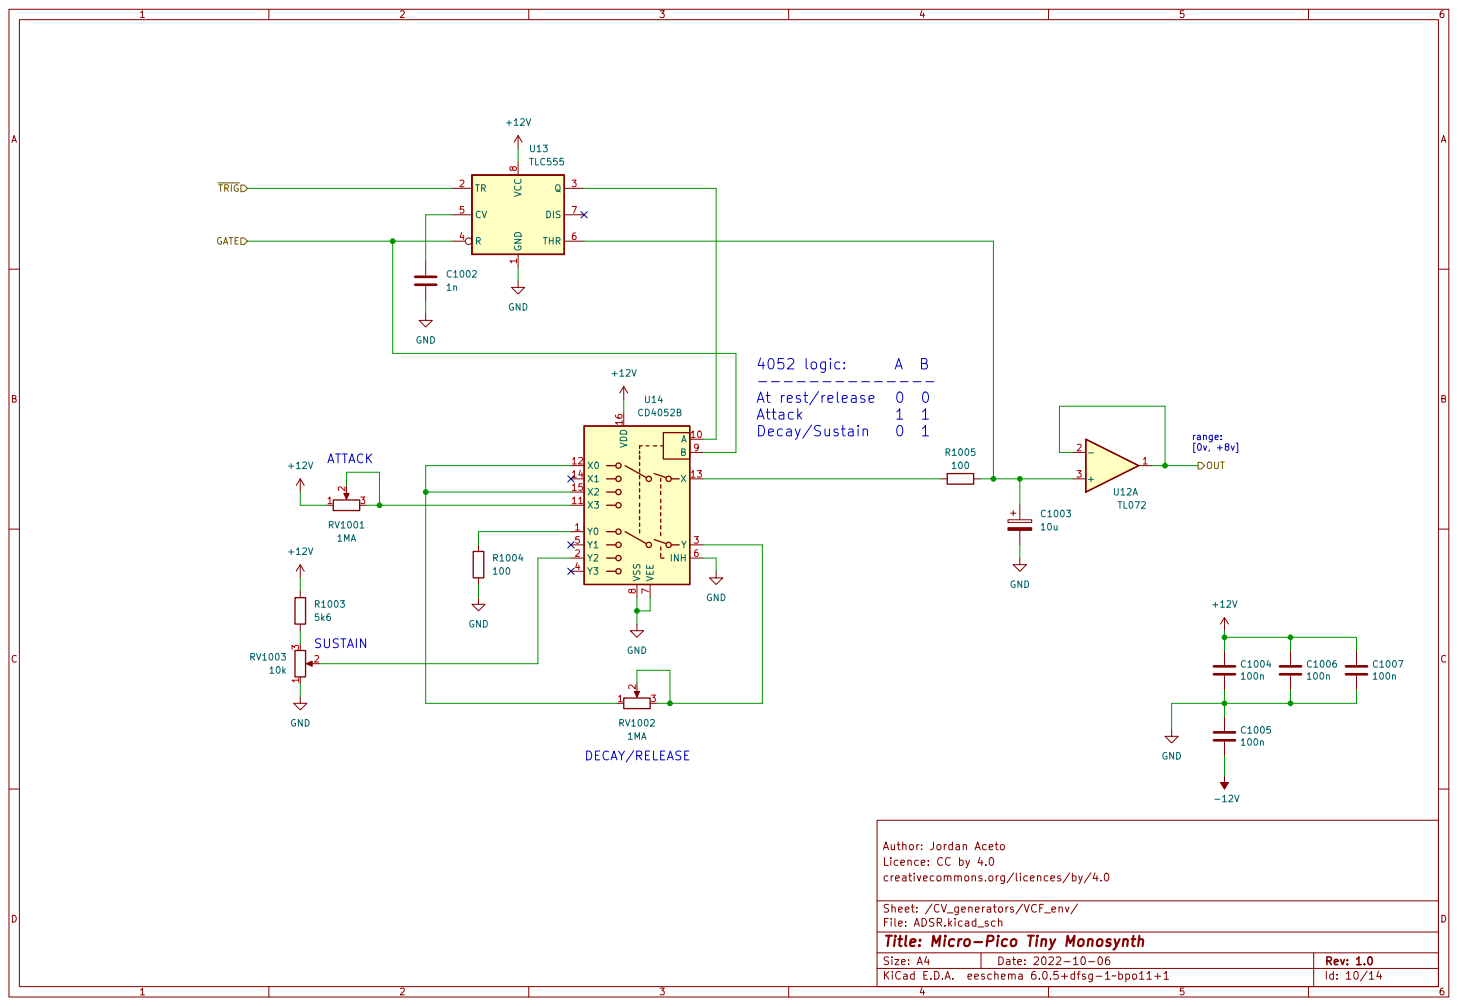
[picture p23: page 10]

Licence: CC by 4.0 Author: Jordan Aceto

creativecommons.org/licences/by/4.0

Sheet: /CV_generators/VCF_env/
File: ADSR.kicad_sch
Id: 10/14 Title: Micro-Pico Tiny Monosynth

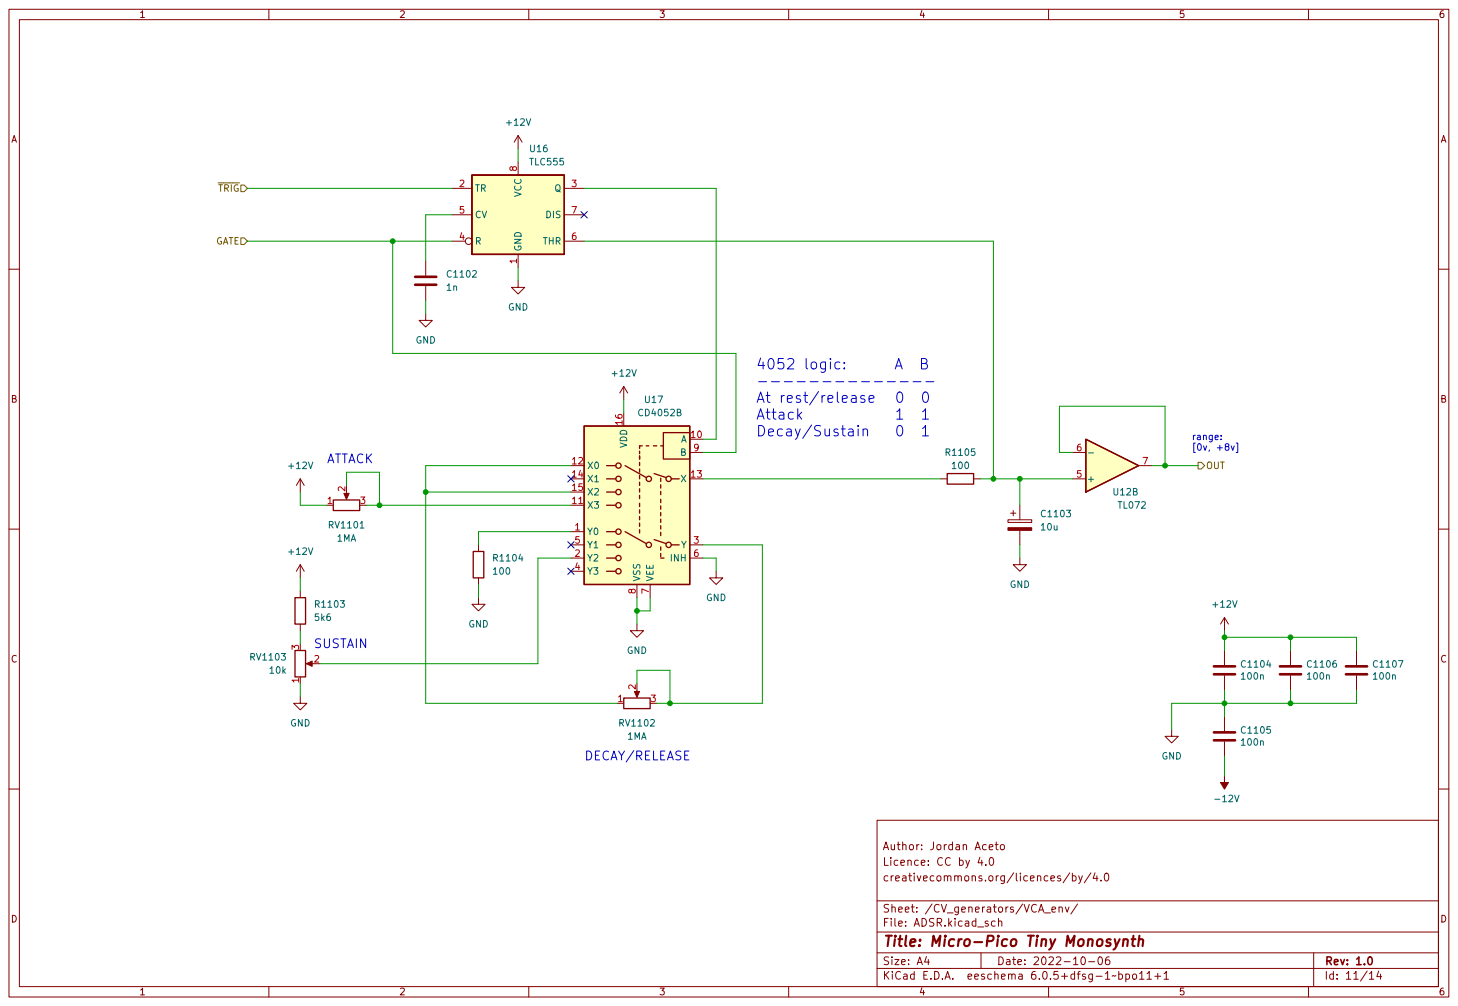
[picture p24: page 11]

Licence: CC by 4.0 Author: Jordan Aceto

creativecommons.org/licences/by/4.0

Sheet: /CV_generators/VCA_env/
File: ADSR.kicad_sch
Id: 11/14 Title: Micro-Pico Tiny Monosynth

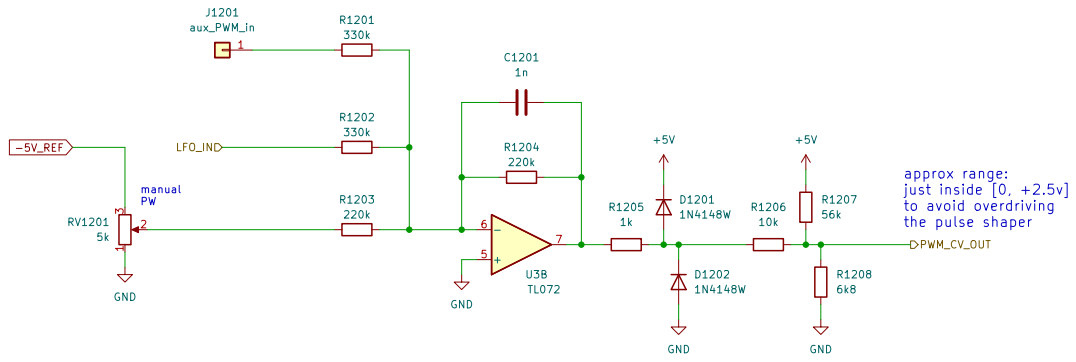
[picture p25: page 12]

Licence: CC by 4.0 Author: Jordan Aceto GND

creativecommons.org/licences/by/4.0

Sheet: /CV_generators/PWM_CV_scaler/
File: PWM_CV_scaler.kicad_sch
Id: 12/14 Title: Micro-Pico Tiny Monosynth


Licence: CC by 4.0 Author: Jordan Aceto

creativecommons.org/licences/by/4.0

Sheet: /CV_generators/VCF_CV_scaler/
File: VCF_CV_scaler.kicad_sch
Id: 13/14 Title: Micro-Pico Tiny Monosynth


2 FB 3 ~{SHDN} 4 SS 5 Vin 6 U1401

Licence: CC by 4.0 Author: Jordan Aceto

creativecommons.org/licences/by/4.0

Sheet: /power_supply/
File: power_supply.kicad_sch
Id: 14/14 Title: Micro-Pico Tiny Monosynth












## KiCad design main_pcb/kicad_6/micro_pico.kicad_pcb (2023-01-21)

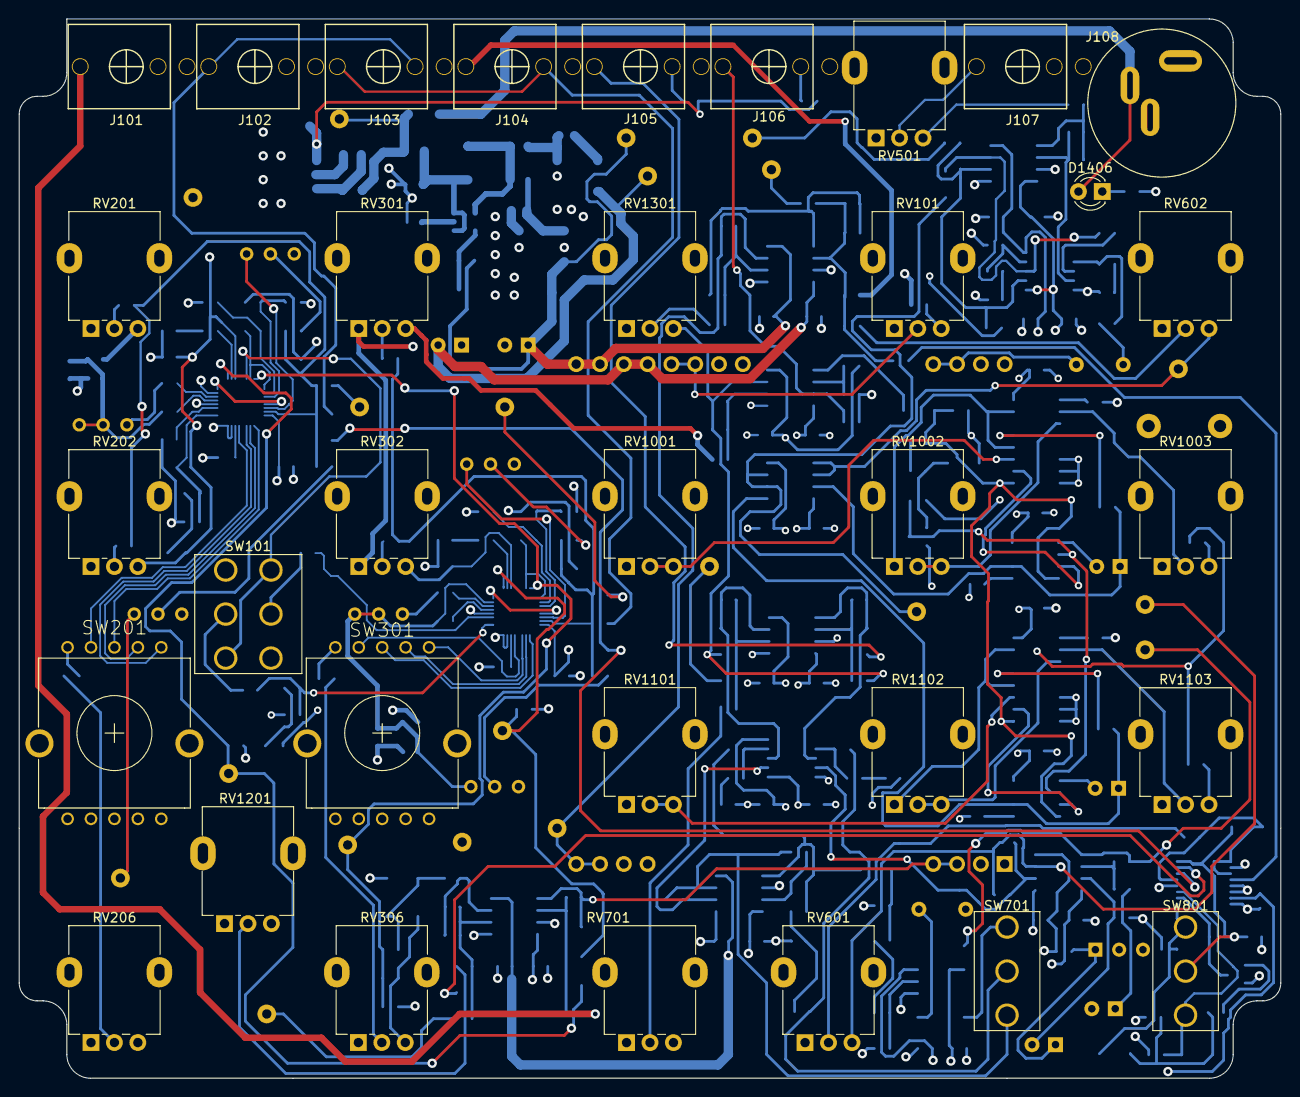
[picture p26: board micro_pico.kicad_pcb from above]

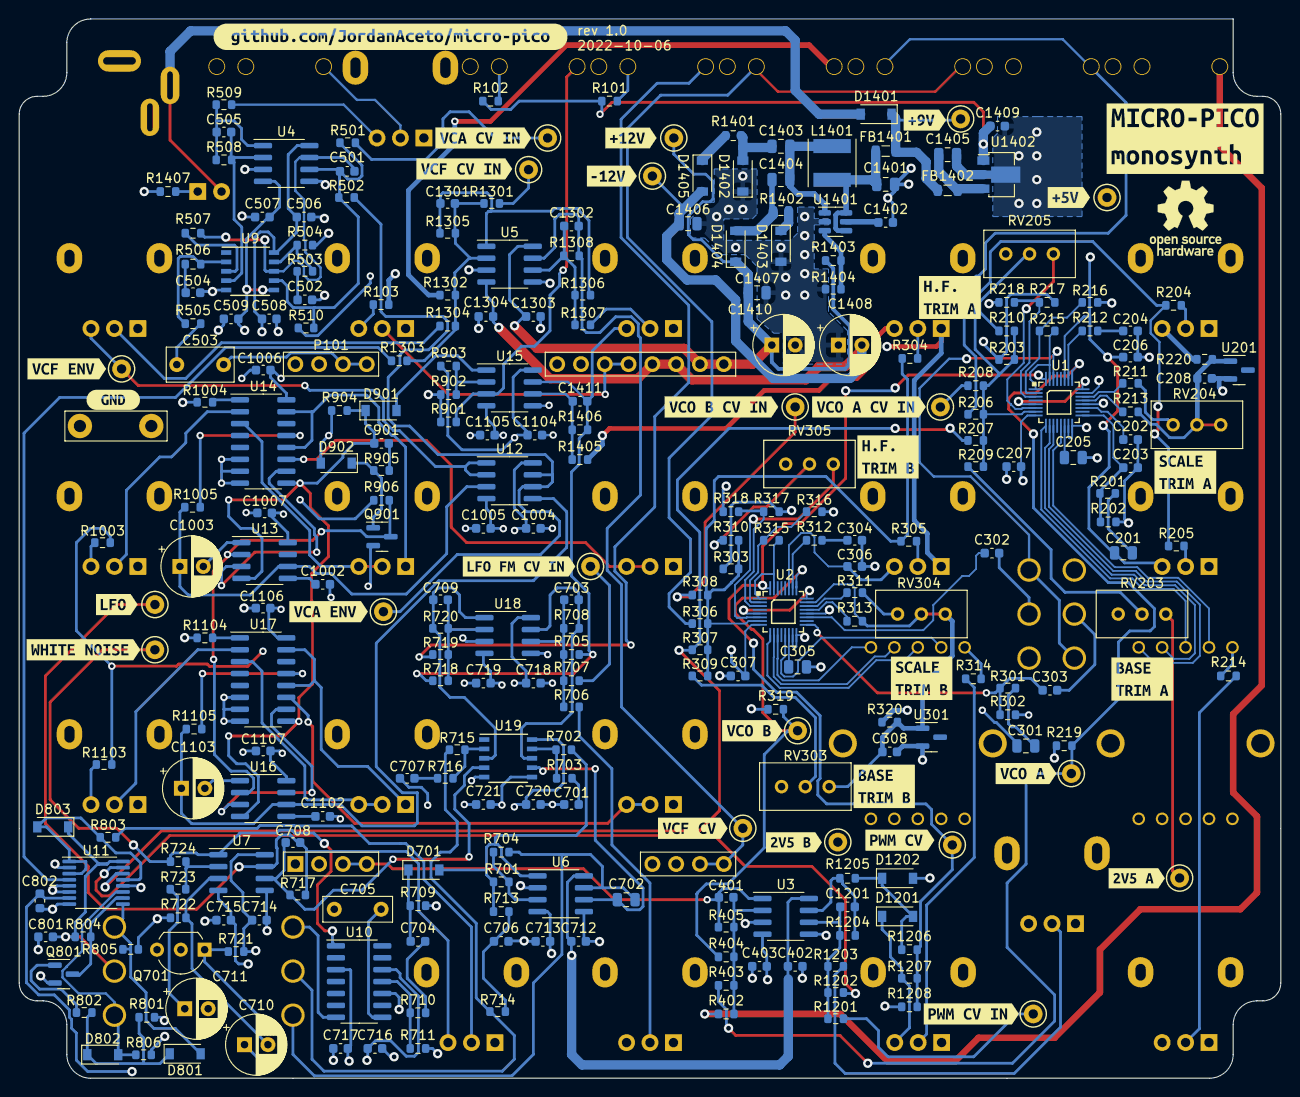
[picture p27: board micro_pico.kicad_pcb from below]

Board: 4 copper layers, 134.6 x 113.0 mm, 332 parts (299 on the bottom side), 182 nets.

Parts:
C201, C301: 10u; C_0805_2012Metric
C202, C203, C204, C302, C303, C304: 10n; C_0603_1608Metric
C205, C305: 3N9 COG; C_0805_2012Metric
C206, C207, C208, C306, C307, C308, C402, C403, C506, C507, C508, C509, C706, C712, C713, C714, C715, C716, C717, C718, C719, C720, C721, C801, C802, C1004, C1005, C1006, C1007, C1104, C1105, C1106, C1107, C1303, C1304, C1402, C1409, C1411: 100n; C_0603_1608Metric
C401, C505, C708, C901, C1302: 100p; C_0603_1608Metric
C501, C502, C504, C701, C703, C704, C707, C709, C1002, C1102, C1201, C1301: 1n; C_0603_1608Metric
C503: 470n; C_Rect_L7.0mm_W3.5mm_P5.00mm
C702: 10n; C_0805_2012Metric
C705: 2n2; C_Rect_L7.2mm_W2.5mm_P5.00mm_FKS2_FKP2_MKS2_MKP2
C710, C711, C1003, C1103, C1408, C1410: 10u; CP_Radial_D6.3mm_P2.50mm
C1401, C1406, C1407: 4u7; C_0805_2012Metric
C1403, C1404: 1u; C_0805_2012Metric
C1405: 470n; C_0805_2012Metric
D701, D801, D802, D803, D901, D902, D1201, D1202: 1N4148W; D_SOD-123
D1401, D1402, D1403, D1404, D1405: B5819W; D_SOD-123
D1406: XLMDK65D; LED_D3.0mm
FB1401, FB1402: 100R @ 100MHz; L_0805_2012Metric
J101, J102, J103, J104, J105, J106, J107: PJ301M-12
J108: PJ-011A; CUI_PJ-011A
J201, J301: aux_FM_in; TestPoint_Keystone_5000-5004_Miniature
J501: aux_AM_in; TestPoint_Keystone_5000-5004_Miniature
J701: white_noise; TestPoint_Keystone_5000-5004_Miniature
J702: aux_LFO_FM_in; TestPoint_Keystone_5000-5004_Miniature
J1201: aux_PWM_in; TestPoint_Keystone_5000-5004_Miniature
J1301: aux_VCF_FM_in; TestPoint_Keystone_5000-5004_Miniature
L1401: 10uH, 1.2A; L_Taiyo-Yuden_NR-50xx
P101: VCF_plug_in_port
Q701: 2N3904_wide; TO-92_Inline_Wide
Q801, Q901: MMBT3904; SOT-23
R101, R220, R320, R723, R803, R1205: 1k; R_0603_1608Metric
R102, R103, R201, R202, R301, R302, R709, R801, R802, R804, R805, R806, R904, R906, R1206, R1407: 10k; R_0603_1608Metric
R203, R303, R708: 39k; R_0603_1608Metric
R204, R304, R707: 200k; R_0603_1608Metric
R205, R305, R722: 2M2; R_0603_1608Metric
R206, R207, R208, R209, R214, R306, R307, R308, R309, R314, R402, R405, R501, R504, R704, R706, R715, R717, R718, R719, R901, R903, R905, R1301, R1302, R1303, R1306, R1308, R1405, R1406: 100k; R_0603_1608Metric
R210, R310: 270k; R_0603_1608Metric
R211, R311, R713, R714: 47k; R_0603_1608Metric
R212, R312, R503, R506, R509, R703, R716: 270; R_0603_1608Metric
R213, R313: 470k; R_0603_1608Metric
R215, R315: 3k9; R_0603_1608Metric
R216, R218, R316, R318, R507, R711: 4k7; R_0603_1608Metric
R217, R317, R508, R710, R902: 12k; R_0603_1608Metric
R219, R319: 18k; R_0603_1608Metric
R403, R404, R505: 27k; R_0603_1608Metric
R502, R721: 150k; R_0603_1608Metric
R510, R724: 10M; R_0603_1608Metric
R701, R1203, R1204, R1307: 220k; R_0603_1608Metric
R702, R1305: 22k; R_0603_1608Metric
R705: 68k; R_0603_1608Metric
R720, R1207, R1304: 56k; R_0603_1608Metric
R1003, R1103: 5k6; R_0603_1608Metric
R1004, R1005, R1104, R1105: 100; R_0603_1608Metric
R1201, R1202: 330k; R_0603_1608Metric
R1208: 6k8; R_0603_1608Metric
R1401, R1402: 1; R_0603_1608Metric
R1403: 114k; R_0603_1608Metric
R1404: 13k3; R_0603_1608Metric
RV101, RV206, RV306, RV1003, RV1103: 10k; Alpha_RD901F
RV201, RV202, RV301, RV302, RV601, RV602, RV701, RV1301: 100k; Alpha_RD901F
RV203, RV204, RV205, RV303, RV304, RV305: 5k; Potentiometer_Bourns_3296W_Vertical
RV501, RV1201: 5k; Bourns_PTV09
RV1001, RV1002, RV1101, RV1102: 1MA; Alpha_RD901F
SW101: SW_DP_on_on_on; DPDT_mini_toggle
SW201, SW301: SR1712F-0204; SR1712F_rotary_switch
SW701, SW801: SW_SPDT_CO; SPDT_mini_toggle
TP102: VCO_A; TestPoint_Keystone_5000-5004_Miniature
TP103: VCO_B; TestPoint_Keystone_5000-5004_Miniature
TP105: VCO_PWM_CV; TestPoint_Keystone_5000-5004_Miniature
TP106: VCF_FM_CV; TestPoint_Keystone_5000-5004_Miniature
TP201, TP301: 2V5; TestPoint_Keystone_5000-5004_Miniature
TP601: VCA_ENV; TestPoint_Keystone_5000-5004_Miniature
TP602: LFO; TestPoint_Keystone_5000-5004_Miniature
TP603: VCF_ENV; TestPoint_Keystone_5000-5004_Miniature
TP1401: +9; TestPoint_Keystone_5000-5004_Miniature
TP1402: -12; TestPoint_Keystone_5000-5004_Miniature
TP1403: +12; TestPoint_Keystone_5000-5004_Miniature
TP1404: +5; TestPoint_Keystone_5000-5004_Miniature
TP1407: GND; TestPoint_Bridge_Pitch7.62mm_Drill1.3mm
U1, U2: SSI2130; PQN32_HandSoldering
U3, U4, U5, U6, U7, U12, U15, U18: TL072; SOIC-8_3.9x4.9mm_P1.27mm
U9, U19: SSI2162; SSOP-10_3.9x4.9mm_P1.00mm
U10: LF398_SOIC14; SOIC-14_3.9x8.7mm_P1.27mm
U11: CD4053; TSSOP-16_4.4x5mm_P0.65mm
U13, U16: TLC555; SOIC-8_3.9x4.9mm_P1.27mm
U14, U17: CD4052B; SOIC-16_3.9x9.9mm_P1.27mm
U201, U301: LM4040C-2.5; SOT-23
U1401: LT3467A; TSOT-23-6
U1402: L78L05_SOT89; SOT-89-3
kibuzzard-62EC6A3A: G***; kibuzzard-62EC6A3A
kibuzzard-62EC6A5B: G***; kibuzzard-62EC6A5B
kibuzzard-62EC69EF: G***; kibuzzard-62EC69EF
kibuzzard-62EDACE7: G***; kibuzzard-62EDACE7
kibuzzard-62EDACF8: G***; kibuzzard-62EDACF8
kibuzzard-62EDADB4: G***; kibuzzard-62EDADB4
kibuzzard-62EE6A0D: G***; kibuzzard-62EE6A0D
kibuzzard-62EE6A9F: G***; kibuzzard-62EE6A9F
kibuzzard-62EE6AE1: G***; kibuzzard-62EE6AE1
kibuzzard-62EE6B39: G***; kibuzzard-62EE6B39
kibuzzard-62EE6BC1: G***; kibuzzard-62EE6BC1
kibuzzard-62EE6CF1: G***; kibuzzard-62EE6CF1
kibuzzard-62EE6D2D: G***; kibuzzard-62EE6D2D
kibuzzard-62EE6D7D: G***; kibuzzard-62EE6D7D
kibuzzard-62EE6D14: G***; kibuzzard-62EE6D14
kibuzzard-62EE6D53: G***; kibuzzard-62EE6D53
kibuzzard-62EE6DEE: G***; kibuzzard-62EE6DEE
kibuzzard-62EE6E32: G***; kibuzzard-62EE6E32
kibuzzard-62EE6FA2: G***; kibuzzard-62EE6FA2
kibuzzard-62EE64B9: G***; kibuzzard-62EE64B9
kibuzzard-62EE65B4: G***; kibuzzard-62EE65B4
kibuzzard-62EE69E1: G***; kibuzzard-62EE69E1
kibuzzard-62EE748D: G***; kibuzzard-62EE748D
kibuzzard-62EE7039: G***; kibuzzard-62EE7039
kibuzzard-62EE7070: G***; kibuzzard-62EE7070
kibuzzard-62FE2A23: G***; kibuzzard-62FE2A23
kibuzzard-633F7F05: G***; kibuzzard-633F7F05
kibuzzard-634019ED: G***; kibuzzard-634019ED
kibuzzard-634019F6: G***; kibuzzard-634019F6

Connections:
+5V: C201.2, C206.1, C301.2, C306.1, C801.1, C1409.1, D803.1 (K), D1201.1 (K), R101.2, R102.2, R103.1, R220.1, R320.1, R804.1, R1207.2, R1405.1, RV201.3, RV202.3, RV206.3, RV301.3, RV302.3, RV306.3, RV701.3, SW801.2, TP1404.1, U1.27 (V+), U2.27 (V+), U11.16 (VDD), U1402.1 (OUT)
+9V: D1401.1 (K), FB1401.1, FB1402.1, TP1401.1
+12V: C402.1, C506.1, C508.1, C712.1, C714.1, C716.1, C718.1, C720.1, C1004.1, C1006.1, C1007.1, C1104.1, C1106.1, C1107.1, C1303.1, C1407.1, C1410.1, D1404.1 (K), P101.9 (V+), P101.10 (V+), R721.1, R903.2, R906.1, R1003.1, R1103.1, R1403.2, RV1001.1, RV1101.1, TP1403.1, U3.8 (V+), U4.8 (V+), U5.8 (V+), U6.8 (V+), U7.8 (V+), U9.10 (V+), U10.12 (V+), U12.8 (V+), U13.8 (VCC), U14.16 (VDD), U15.8 (V+), U16.8 (VCC), U17.16 (VDD), U18.8 (V+), U19.10 (V+)
-5V_REF: C1411.2, R504.2, R510.2, R705.2, R718.2, R1406.2, RV201.1, RV202.1, RV301.1, RV302.1, RV1201.3, RV1301.3, U15.7
-12V: C207.2, C307.2, C403.2, C507.2, C509.2, C713.2, C715.2, C717.2, C719.2, C721.2, C802.2, C1005.2, C1105.2, C1304.2, C1406.2, C1408.2, D1405.2 (A), P101.11 (V-), P101.12 (V-), TP1402.1, U1.8 (V-), U2.8 (V-), U3.4 (V-), U4.4 (V-), U5.4 (V-), U6.4 (V-), U7.4 (V-), U9.6 (V-), U10.3 (V-), U11.7 (VEE), U12.4 (V-), U15.4 (V-), U18.4 (V-), U19.6 (V-)
/CV_generators/GATE_IN: J106.3, R901.1, U15.3 (+)
/CV_generators/LFO/HI_Z_SQUARE: R714.2, R715.2, SW701.2
/CV_generators/LFO/OUT: C708.1, R717.1, RV601.3, TP602.1, U7.7
/CV_generators/LFO/RAW_SQUARE: D701.2 (A), R701.2, R702.2, R713.1, U6.1
/CV_generators/LFO/S&H: SW701.3, U10.7
/CV_generators/LFO/TRIANGLE: C702.2, R704.2, SW701.1, U6.7
/CV_generators/LFO/WHITE_NOISE: J701.1, R724.2, U7.1, U10.1 (I)
/CV_generators/LFO_DEPTH_CV: J105.3, R719.2
/CV_generators/LFO_switching/LFO_IN: R803.1, RV601.2
/CV_generators/LFO_switching/LFO_TO_PWM: R1202.1, U11.15 (Y)
/CV_generators/LFO_switching/LFO_TO_VCF: R1303.1, U11.4 (Z)
/CV_generators/VCA_CV: R502.2, TP601.1, U12.6 (-), U12.7
/CV_generators/VCA_env/GATE: C901.1, D901.1 (K), R904.1, U13.4 (R), U14.9 (B), U16.4 (R), U17.9 (B)
/CV_generators/VCA_env/~TRIG: Q901.3 (C), R906.2, U13.2 (TR), U16.2 (TR)
/CV_generators/VCF_CV_IN: J104.3, R1302.1
/CV_generators/VCF_CV_scaler/VCF_ENV_IN: R1304.1, RV602.2
/CV_generators/VCF_FM_CV: C1302.2, P101.7 (F_CV_IN), P101.8 (F_CV_IN), R1308.2, TP106.1, U5.7
/CV_generators/VCF_env/OUT: RV602.3, TP603.1, U12.1, U12.2 (-)
/PWM_CV: R1206.2, R1207.1, R1208.2, TP105.1, U1.32 (pwm_in_+), U2.32 (pwm_in_+)
/RAW_9VDC: D1401.2 (A), D1406.2 (A), J108.2
/VCA/SIGNAL_IN: C503.1, P101.17 (SIG_OUT), P101.18 (SIG_OUT)
/VCA/SIGNAL_OUT: J107.3, RV501.2
/VCO_A/LOCAL_2V5_REF: C208.1, R203.2, R213.2, R217.2, R220.2, RV203.3, RV204.2, RV204.3, TP201.1, U1.23 (vref), U201.1 (K)
/VCO_A/SWITCHED_OUT: R219.2, R403.1, TP102.1, U1.25 (mix_out)
/VCO_A/V_PER_OCT_IN_1: J102.3, J103.2, R206.2
/VCO_A_PULSE: SW101.1 (A), SW101.6 (C), U1.30 (pulse_out)
/VCO_B/HARD_SYNC_IN: C303.2, SW101.2 (B)
/VCO_B/LOCAL_2V5_REF: C308.1, R303.2, R313.2, R317.2, R320.2, RV303.3, RV304.2, RV304.3, TP301.1, U2.23 (vref), U301.1 (K)
/VCO_B/SOFT_SYNC_IN: C302.2, SW101.5 (B)
/VCO_B/SWITCHED_OUT: R319.2, R404.1, TP103.1, U2.25 (mix_out)
/VCO_B/V_PER_OCT_IN_1: J103.3, J104.2, R306.2
/VCO_FM_CV: R207.2, R307.2, U11.14 (X)
/audio_mixer/EXT_AUDIO_IN: J101.3, R402.1
/audio_mixer/MIX_OUT: C401.2, P101.3 (SIG_IN), P101.4 (SIG_IN), R405.2, U3.1
GND: C202.2, C203.2, C204.2, C205.2, C206.2, C207.1, C208.2, C304.2, C305.2, C306.2, C307.1, C308.2, C402.2, C403.1, C502.2, C504.2, C506.2, C507.1, C508.2, C509.1, C701.2, C705.2, C706.2, C707.2, C711.2, C712.2, C713.1, C714.2, C715.1, C716.2, C717.1, C718.2, C719.1, C720.2, C721.1, C801.2, C802.1, C1002.2, C1003.2, C1004.2, C1005.1, C1006.2, C1007.2, C1102.2, C1103.2, C1104.2, C1105.1, C1106.2, C1107.2, C1303.2, C1304.1, C1401.2, C1402.2, C1405.2, C1406.1, C1407.2, C1408.1, C1409.2, C1410.2, D902.2 (A), D1202.2 (A), D1402.1 (K), D1403.2 (A), J101.1, J101.2, J102.1, J102.2, J103.1, J104.1, J105.1, J106.1, J107.1, J108.1, P101.1 (GND), P101.2 (GND), P101.5 (GND), P101.6 (GND), P101.15 (GND), P101.16 (GND), P101.19 (GND), P101.20 (GND), Q701.2 (B), Q801.2 (E), Q901.2 (E), R202.2, R216.1, R218.1, R219.1, R302.2, R316.1, R318.1, R319.1, R709.2, R711.2, R722.2, R801.2, R805.2, R806.2, R901.2, R902.1, R904.2, R1004.2, R1104.2, R1208.1, R1404.1, R1407.1, RV101.1, RV203.1, RV205.1, RV206.1, RV303.1, RV305.1, RV306.1, RV501.1, RV601.1, RV602.1, RV701.1, RV1003.1, RV1103.1, RV1201.1, RV1301.1, SW101.3 (C), SW101.4 (A), TP1407.1, U1.15 (dgnd), U1.16 (agnd), U1.20 (hft_base), U2.15 (dgnd), U2.16 (agnd), U2.20 (hft_base), U3.3 (+), U3.5 (+), U4.3 (+), U4.5 (+), U5.3 (+), U5.5 (+), U6.2 (-), U6.5 (+), U7.5 (+), U9.5 (GND), U10.10 (T), U11.2 (Y0), U11.5 (Z0), U11.6 (Inh), U11.8 (VSS), U11.12 (X0), U13.1 (GND), U14.6 (INH), U14.7 (VEE), U14.8 (VSS), U15.5 (+), U16.1 (GND), U17.6 (INH), U17.7 (VEE), U17.8 (VSS), U18.3 (+), U18.5 (+), U19.5 (GND), U201.2 (A), U301.2 (A), U1401.2 (GND), U1402.2 (GND)
unnamed: C201.1, R201.1
unnamed: C202.1, U1.19 (soft_sync)
unnamed: C203.1, R201.2, R202.1, U1.17 (hard_sync)
unnamed: C204.1, R212.2
unnamed: C205.1, U1.14 (tcap)
unnamed: C301.1, R301.1
unnamed: C302.1, U2.19 (soft_sync)
unnamed: C303.1, R301.2, R302.1, U2.17 (hard_sync)
unnamed: C304.1, R312.2
unnamed: C305.1, U2.14 (tcap)
unnamed: C401.1, R402.2, R403.2, R404.2, R405.1, U3.2 (-)
unnamed: C501.1, R507.1, U4.7, U9.8
unnamed: C501.2, R501.2, R502.1, R510.1, U4.6 (-), U9.7
unnamed: C502.1, R503.2
unnamed: C503.2, R505.2
unnamed: C504.1, R506.2
unnamed: C505.1, R508.1, R509.1, U4.1
unnamed: C505.2, R508.2, U4.2 (-), U9.4
unnamed: C701.1, R703.2
unnamed: C702.1, U6.6 (-), U19.7
unnamed: C703.1, R708.2, U18.7, U19.8
unnamed: C703.2, R705.1, R706.2, R707.1, R708.1, U18.6 (-)
unnamed: C704.1, D701.1 (K), R709.1
unnamed: C704.2, R710.1
unnamed: C705.1, U10.8 (Ch)
unnamed: C706.1, R713.2, R714.1
unnamed: C707.1, R716.2
unnamed: C708.2, R717.2, U7.6 (-), U19.4
unnamed: C709.1, R720.2, U18.1, U19.3
unnamed: C709.2, R718.1, R719.1, R720.1, U18.2 (-)
unnamed: C710.1, Q701.1 (E), R721.2
unnamed: C710.2, R722.1, U7.3 (+)
unnamed: C711.1, R723.2
unnamed: C901.2, R905.1
unnamed: C1002.1, U13.5 (CV)
unnamed: C1003.1, R1005.2, U12.3 (+), U13.6 (THR)
unnamed: C1102.1, U16.5 (CV)
unnamed: C1103.1, R1105.2, U12.5 (+), U16.6 (THR)
unnamed: C1201.1, R1201.2, R1202.2, R1203.2, R1204.1, U3.6 (-)
unnamed: C1201.2, R1204.2, R1205.1, U3.7
unnamed: C1301.1, R1301.2, R1302.2, R1303.2, R1304.2, R1305.1, U5.2 (-)
unnamed: C1301.2, R1305.2, R1306.1, U5.1
unnamed: C1302.1, R1306.2, R1307.2, R1308.1, U5.6 (-)
unnamed: C1401.1, FB1401.2, L1401.1, U1401.4 (~SHDN), U1401.6 (Vin)
unnamed: C1402.1, U1401.5 (SS)
unnamed: C1403.1, C1404.2, L1401.2, U1401.1 (SW)
unnamed: C1403.2, D1402.2 (A), R1401.1
unnamed: C1404.1, D1404.2 (A), R1402.2
unnamed: C1405.1, FB1402.2, U1402.3 (IN)
unnamed: C1411.1, R1405.2, R1406.1, U15.6 (-)
unnamed: D801.1 (K), D802.1 (K), R801.1, R802.1
unnamed: D801.2 (A), R805.1, SW801.3, U11.9 (C)
unnamed: D802.2 (A), R806.1, SW801.1, U11.11 (A)
unnamed: D803.2 (A), R803.2, U11.1 (Y1), U11.3 (Z1), U11.13 (X1)
unnamed: D901.2 (A), U15.1
unnamed: D902.1 (K), Q901.1 (B), R905.2
unnamed: D1201.2 (A), D1202.1 (K), R1205.2, R1206.1
unnamed: D1403.1 (K), R1402.1
unnamed: D1405.1 (K), R1401.2
unnamed: D1406.1 (K), R1407.2
unnamed: J105.2, R101.1
unnamed: J106.2, R102.1
unnamed: J201.1, R208.1
unnamed: J301.1, R308.1
unnamed: J501.1, R501.1
unnamed: J702.1, R707.2
unnamed: J1201.1, R1201.1
unnamed: J1301.1, R1301.1
unnamed: P101.13 (Q_CV_IN), P101.14 (Q_CV_IN), RV101.2
unnamed: Q801.1 (B), R802.2
unnamed: Q801.3 (C), R804.2, U11.10 (B)
unnamed: R103.2, RV101.3
unnamed: R203.1, R204.1, R205.1, R206.1, R207.1, R208.2, R209.1, R210.2, U1.7 (expo_freq)
unnamed: R204.2, RV201.2
unnamed: R205.2, RV202.2
unnamed: R209.2, RV203.2
unnamed: R210.1, RV205.2
unnamed: R211.1, RV204.1
unnamed: R211.2, U1.22 (expo_scale)
unnamed: R212.1, U1.26 (bw_comp)
unnamed: R213.1, U1.21 (lin_freq)
unnamed: R214.1, RV206.2
unnamed: R214.2, SW201.1
unnamed: R215.1, R216.2, U1.2 (sine_in_+)
unnamed: R215.2, U1.1 (tri_out), U1.31 (pwm_in_-)
unnamed: R217.1, R218.2, U1.3 (sine_in_-)
unnamed: R303.1, R304.1, R305.1, R306.1, R307.1, R308.2, R309.1, R310.2, U2.7 (expo_freq)
unnamed: R304.2, RV301.2
unnamed: R305.2, RV302.2
unnamed: R309.2, RV303.2
unnamed: R310.1, RV305.2
unnamed: R311.1, RV304.1
unnamed: R311.2, U2.22 (expo_scale)
unnamed: R312.1, U2.26 (bw_comp)
unnamed: R313.1, U2.21 (lin_freq)
unnamed: R314.1, RV306.2
unnamed: R314.2, SW301.1
unnamed: R315.1, R316.2, U2.2 (sine_in_+)
unnamed: R315.2, U2.1 (tri_out), U2.31 (pwm_in_-)
unnamed: R317.1, R318.2, U2.3 (sine_in_-)
unnamed: R503.1, R504.1, U9.9
unnamed: R505.1, R506.1, U9.2
unnamed: R507.2, U9.3
unnamed: R509.2, RV501.3
unnamed: R701.1, R704.1, U6.3 (+)
unnamed: R702.1, R703.1, U19.9
unnamed: R706.1, RV701.2
unnamed: R710.2, R711.1, U10.11 (Hold)
unnamed: R715.1, R716.1, U19.2
unnamed: R723.1, R724.1, U7.2 (-)
unnamed: R902.2, R903.1, U15.2 (-)
unnamed: R1003.2, RV1003.3
unnamed: R1004.1, U14.1 (Y0)
unnamed: R1005.1, U14.13 (X)
unnamed: R1103.2, RV1103.3
unnamed: R1104.1, U17.1 (Y0)
unnamed: R1105.1, U17.13 (X)
unnamed: R1203.1, RV1201.2
unnamed: R1307.1, RV1301.2
unnamed: R1403.1, R1404.2, U1401.3 (FB)
unnamed: RV205.3, U1.6 (hf_track)
unnamed: RV305.3, U2.6 (hf_track)
unnamed: RV1001.2, RV1001.3, U14.11 (X3)
unnamed: RV1002.1, U14.12 (X0), U14.15 (X2)
unnamed: RV1002.2, RV1002.3, U14.3 (Y)
unnamed: RV1003.2, U14.2 (Y2)
unnamed: RV1101.2, RV1101.3, U17.11 (X3)
unnamed: RV1102.1, U17.12 (X0), U17.15 (X2)
unnamed: RV1102.2, RV1102.3, U17.3 (Y)
unnamed: RV1103.2, U17.2 (Y2)
unnamed: SW201.2, U1.13 (aux_2_mix)
unnamed: SW201.3, U1.9 (tri_mix)
unnamed: SW201.4, U1.10 (saw_mix)
unnamed: SW201.5, U1.11 (pulse_mix)
unnamed: SW301.2, U2.13 (aux_2_mix)
unnamed: SW301.3, U2.9 (tri_mix)
unnamed: SW301.4, U2.10 (saw_mix)
unnamed: SW301.5, U2.11 (pulse_mix)
unnamed: U1.5 (aux_in_2), U1.24 (sine_out)
unnamed: U2.5 (aux_in_2), U2.24 (sine_out)
unnamed: U13.3 (Q), U14.10 (A)
unnamed: U16.3 (Q), U17.10 (A)

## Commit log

2022-08-18 Fix schematic link
2022-08-24 Update README, note about current status of files
2022-09-09 Update rev 0.1, fix VCA tails, add local 2v5 regs, change some pot footprints
    [ADSR.kicad_sch, CV_generators.kicad_sch, LFO.kicad_sch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]
2022-09-17 Change 555 timer type, fixes odd ADSR behavior
    [ADSR.kicad_sch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]
2023-01-21 Add mod-wheel VCA, fix occasional VCO freq locking
    [ADSR.kicad_sch, CV_generators.kicad_sch, LFO.kicad_sch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]
2023-01-21 Fix cropped SVG drill guide
2023-01-21 SVG drill guide fix round 2
